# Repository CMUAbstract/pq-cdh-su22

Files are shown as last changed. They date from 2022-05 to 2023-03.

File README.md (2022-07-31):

# Pocketqube Command and Data Handling Board

Pocketqube command and data handling board

**Dependencies**

```bash
sudo apt install build-essential cmake gcc git libusb-1.0-0 libusb-1.0-0-dev libgtk-3-dev
cd $HOME/git-repos/cote/scripts
./setup_dependencies.sh $HOME/sw
```

## Useful link

* [libopencm3](http://libopencm3.org/docs/latest/stm32l4/html/modules.html) : STM open source firmware link

## Directory Contents

* [3d-models](3d-models/README.md): Contains copies of `.stp` 3D model files
* [components](components/README.md): Contains copies of `.lib` component files
* [datasheets](datasheets/README.md): Contains component datasheets
* [footprints](footprints/README.md): Contains copies of `.kicad_mod` footprint
  files
* [gerbers](gerbers/README.md): Contains the most recent set of Gerber files
* [kicad](kicad/README.md): Contains the KiCad project files
* [versions](versions/README.md): Contains `.zip` files of Gerber files
  submitted for manufacture
* [BOM.csv](BOM.csv): Bill of materials
* [LICENSE](LICENSE): License
* [NOTES.md](NOTES.md): Step-by-step instructions for setting up KiCad,
  designing the board, and exporting Gerber files for manufacture
* [README.md](README.md): This document

## License

Written by Bradley Denby  
Other contributors: None

## Update

PQ-CDH Version 0.1.0 : 

1. Transferred design scheamtic and PCB from Kicad5 to Kicad6
2. Mounting holes adjustment same as referred to comm-401 board.
3. Reduced board dimension 43 x 43 mm
4. Removing 5th Pin from upper and lower right

PQ-CDH Version 0.1.1

1. Changed VDD, GND, SWDIO, and SWCLK to lower left to right 4 pins
2. Changed "PQ CDH v0.1.0" to "PQ CDH v0.1.1"
3. Adjusted controller and Conn_02x06_Odd_Even, for mounting hole clearance.
4. Adjusted Conn_02x06_Odd_Even in vertically aligned along with aligned to top and bottom connector holes.
5. Addition of 4 testpads added between oscillator and its capacitor.

PQ-CDH Version 0.2.0

1. I2C3 SDA and SCL to pins 1 and 2 on the bottom header row
2. ADC to pin 3 on the bottom header row
3. unused GPIO to pins 4 and 5 on bottom header row

See the top-level [LICENSE](LICENSE) file for the license.

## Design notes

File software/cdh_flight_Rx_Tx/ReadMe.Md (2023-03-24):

# FLATSAT DEMO CODE : CDH

This repositry includes support for openLST TAB communication protocol
1. Generates control signal for EPS board to control COM board power supply.
2. Receives TAB commands over UART, parses TAB commands to formulate reply and sends TAB commands over UART.
3. Control CDH LEDs for TAB commmands reception, enables debugging.

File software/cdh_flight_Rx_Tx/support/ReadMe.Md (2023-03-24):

# Support Includes : Flatsat DEMO CDH

- `bootloader` : Tartan Artibeus EXPT board bootloader implementation file - USART1 Tx, Rx for TAB command receive, parse response and reply.
- `commands` : Tartan Artibeus EXPT board commands file
- `support` : Tartan Artibeus CDH board UART support implementation - init clock, init led, init uart
- `taolst_protocol`: Tartan Artibeus OLST serial communication protocol implementation - Rx/Tx Buffer and commands

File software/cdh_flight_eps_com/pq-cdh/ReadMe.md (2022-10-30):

Support file : iniialisation for Clock, UART and LED pins

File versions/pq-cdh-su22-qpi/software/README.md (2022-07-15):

# Command and Data Handling Board Software

Command and data handling board software

**Usage**

Change directories to one of the software folders, e.g. `blink`, and execute
`make`. The Makefile includes the rules.mk file, as well as libopencm3 and any
common ASM or C files. Be sure to source `sourcefile.txt` first.

```bash
# Example
cd $HOME/git-repos/pq-cdh-su22/scripts/
source sourcefile.txt
cd $HOME/git-repos/pq-cdh-su22/software/blink/
make
```

See the README in each program directory for details.

## Directory Contents

* [blink](blink/README.md): Makes the Tartan Artibeus EXPT board LEDs blink
* [rules.mk](rules.mk): Used by `make`
* [README.md](README.md): This document

## License

Written by Bradley Denby  
Other contributors: None

See the top-level LICENSE file for the license.

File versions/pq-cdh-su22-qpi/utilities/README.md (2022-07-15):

# Utilities

This directory contains utilities. The setup script places the stlink software
and the ARM GCC compiler in this directory.

## Directory Contents

* [README.md](README.md): This document

## License

Written by Bradley Denby  
Other contributors: None

See the top-level LICENSE file for the license.

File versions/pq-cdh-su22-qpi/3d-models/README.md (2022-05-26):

# 3D Models

3D model files for board components

## Directory Contents

* [README.md](README.md): This document

## License

Written by Bradley Denby  
Other contributors: None

See the top-level [../LICENSE](LICENSE) file for the license.

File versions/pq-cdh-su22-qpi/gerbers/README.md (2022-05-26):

# Gerbers

Gerber files for the most recent board version

## Directory Contents

* [README.md](README.md): This document

## License

Written by Bradley Denby  
Other contributors: None

See the top-level [../LICENSE](LICENSE) file for the license.

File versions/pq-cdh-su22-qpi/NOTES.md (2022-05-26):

# Notes for KiCad

* Install the correct version.

```bash
sudo add-apt-repository ppa:kicad/kicad-6.0-releases
sudo apt update
sudo apt install kicad
```

* Open KiCad. If prompted, start with default settings.

* Choose `File > New Project from Template...`. Select the project location.
  **Un-check "Create a new directory for the project" (bottom left)** and type
  the project name in the top text box (here: `pq-cdh`). Choose "Save."

* Launch the Schematic Editor. If prompted, accept "Copy default global symbol
  library table (recommended)." Choose `File > Page Settings...` and select
  "Size: USLetter 8.5x11in" if not already selected. Choose `File > Save`.

* Open the Symbol Editor by choosing `Tools > Symbol Editor` from the Schematic
  Editor.

* Using the Symbol Editor, choose `File > New Library...`. Choose the "Project"
  scope when prompted. Use the project name (here: `pq-cdh`), and choose "Save."

* Import the BOM symbols provided by `componentsearchengine.com` (free account
  required). Select `File > Import Symbol...` and save in the project library
  (be sure to select the project library for symbol import). Copies of the
  `.lib` files should be placed in the `components/` directory.

* Open the Footprint Editor. Accept "Copy default global footprint library table
  (recommended)" if prompted. Choose `File > New Library...`. Choose the
  "Project" scope when prompted. Use the project name (here: `pq-cdh`), and
  choose "Save."

* Import the BOM footprints from `componentsearchengine.com` into the project
  footprint library. Right-click on the footprint library, and select
  `Import Footprint...`. Copies of the `.kicad_mod` files should be placed in
  the `footprints/` directory. Choose `File > Save`, select the footprint
  library, and choose "Save."

* For each footprint, associate the corresponding 3D model from the `3d-models/`
  directory. Choose `File > Footprint Properties...` and specify the path to the
  3D model file under the 3D Settings tab using the folder icon. Save changes.

* Lay out the schematic in the Schematic Editor. Set the appropriate label
  values.

* In the Schematic Editor, select `Tools > Annotate Schematic...` and choose
  "Entire schematic;" "Keep existing annotations;" "Sort symbols by X position;"
  and "Use first free number after 0."

* Also in the Schematic Editor, choose `Tools > Assign Footprints...` and set
  the footprints.

* Specify footprints that cannot be set automatically, e.g.:
  `Conn_01x04 : pq:PinSocket_4x1_Pocketqube`, and
  `Conn_01x16 : pq:PinSocket_1x16_Pocketqube`, and
  `Conn_01x04 : pq:MountingHoles_Pocketqube`

* Open the PCB Editor and choose `File > Page Settings...` to select
  "Size: USLetter 8.5x11in" if not already selected. Choose `File > Save`.

* Choose `File > Board Setup...` and under "Layers," choose "Four layers, parts
  on Front & Back." Enable the following layers: `F.CrtYd`, `F.Fab`, `F.Paste`,
  `F.SilkS`, `F.Mask`, `F.Cu`, `In1.Cu`, `In2.Cu`, `B.Cu`, `B.Mask`, `B.SilkS`,
  `B.Paste`, `B.Fab`, `B.CrtYd`, `Edge.Cuts`, and `Margin`. For simplicity, set
  `In1.Cu` and `In2.Cu` to power layers and keep the other two layers as signal
  layers. Set the PCB thickness to 1.742 mm.

* Choose `Preferences > Preferences...`. Under `Pcbnew`, set Units to Inches.

* Choose `File > Board Setup...`. Under `Design Rules`, choose
  `Solder Mask/Paste`. Set "Solder mask clearance" to 0.0005 in (i.e. 0.5 mils
  or 0.0127 mm), and set all other values to zero.

* Still under `File > Board Setup...`, choose `Design Rules`. Ensure that "Allow
  blind/buried vias" is **not** checked. Ensure that "Allow micro vias (uVias)"
  is **not** checked. Set the following minimum values:
  * Minimum track width: 5 mils
  * Minimum via diameter: 18 mils
  * Minimum via drill: 10 mils
  * Minimum uVia diameter: 18 mils
  * Minimum uVia drill: 10 mils
  * Minimum hole to hole: 5 mils

* Still under `File > Board Setup...`, choose `Net Classes` under
  `Design Rules`. Double-click at the top of the entry area under "Net Classes"
  and edit the Default values:
  * Clearance: 5 mils
  * Track Width: 5 mils
  * Via Size: 18 mils
  * Via Drill: 10 mils
  * uVia Size: 18 mils
  * uVia Drill: 10 mils
  * dPair Width: 5 mils
  * dPair Gap: 5 mils

* Still under `File > Board Setup...`, choose `Tracks & Vias` under
  `Design Rules`. Add an 8 mils Tracks Width (for VDD and GND).

* Choose `Preferences > Preferences...`. Under `Pcbnew`, set Units to
  Millimeters.

* Add the PCB outline with graphic lines and graphic arcs.

**Graphic Lines for PCB Edge**

Create the following in the Edge.Cuts layer:
* Start: (136.04, 86.50); End: (173.96, 86.50)
* Start: (136.04,129.50); End: (173.96,129.50)
* Start: (133.50, 89.04); End: (133.50,126.96)
* Start: (176.50, 89.04); End: (176.50,126.96)

**Graphic Arcs for PCB Edge**

Create the following in the Edge.Cuts layer:
* Center: (136.04, 89.04); Start: (136.04, 86.50); Arc angle -90.0
* Center: (173.96, 89.04); Start: (176.50, 89.04); Arc angle -90.0
* Center: (136.04,126.96); Start: (133.50,126.96); Arc angle -90.0
* Center: (173.96,126.96); Start: (173.96,129.50); Arc angle -90.0

* In the Schematic Editor, choose `File > Export > Netlist...` and select
  "Export Netlist."

* In the PCB Editor, choose `File > Import > Netlist...` and browse to the
  appropriate file.

* Place the components, tracks, ground plane, and silkscreen labels.

* Record component characteristics:
  * J1:   (155.00,  88.95) @   0.0 (Example 1)
  * J2:   (155.00, 127.05) @   0.0 (Example 2)
  * J3:   (135.95, 120.70) @ 180.0 (Example 3)
  * J4:   (170.24, 108.00) @ 180.0 (Example 4)
  * J5:   (155.00, 108.00) @   0.0 (Example 5)

* Record via positions:
  * GND: (137.30, 111.30) (Example)

* Ground and power planes (Add filled zones):
  * Clearance: 0.254 mm
  * Minimum width: 0.127 mm
  * Thermal clearance: 0.254 mm
  * Thermal spoke width: 0.254 mm

* Silkscreen labels (Width: 0.5 mm; Height: 0.5 mm; Thickness: 0.1 mm):

## Generating Gerbers

* Ensure that fill zones have been redrawn, e.g. by running DRC (the bug icon)
* Choose `File > Plot...` from the PCB Editor
  * Output directory: ../gerbers/
  * Included Layers: F.Cu, B.Cu, F.Silkscreen, B.Silkscreen, F.Mask, B.Mask,
    Edge.Cuts
  * General Options: Plot footprint values, Plot reference designators
  * Gerber Options: Generate Gerber job file
* Choose "Plot"
* Choose "Generate Drill File"
  * Output folder: ../gerbers/
  * Drill File Format: Excellon, PTH and NPTH in single file, Oval Holes Drill
    Mode: Use route command (recommended)
  * Map File Format: PostScript
  * Dill Origin: Absolute
  * Drill Units: Inches
  * Zeros Format: Decimal format (recommended)
* Choose "Generate Drill File"

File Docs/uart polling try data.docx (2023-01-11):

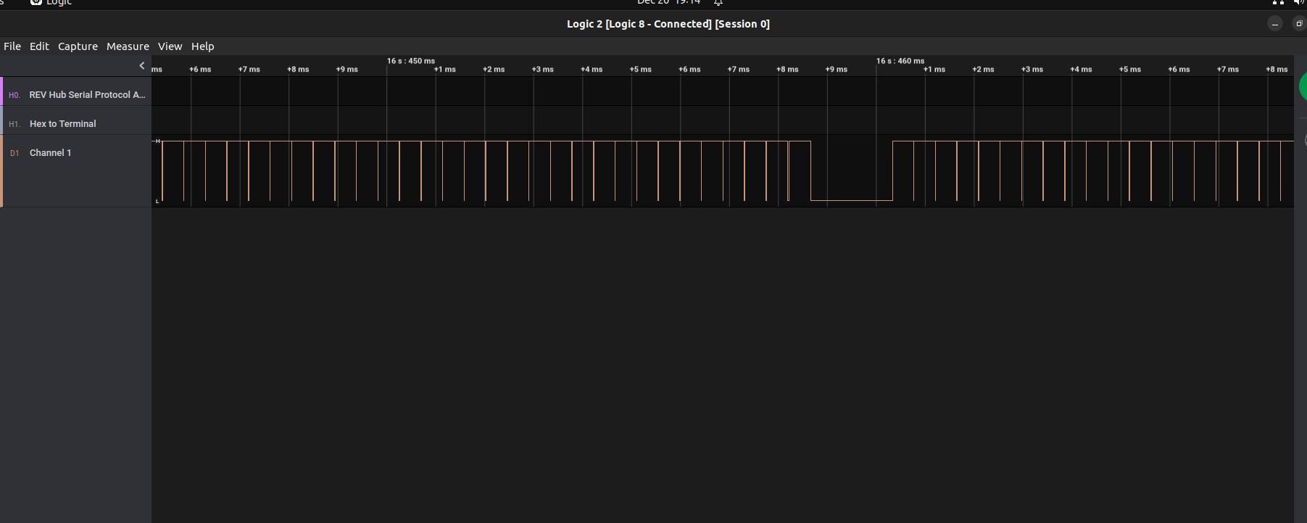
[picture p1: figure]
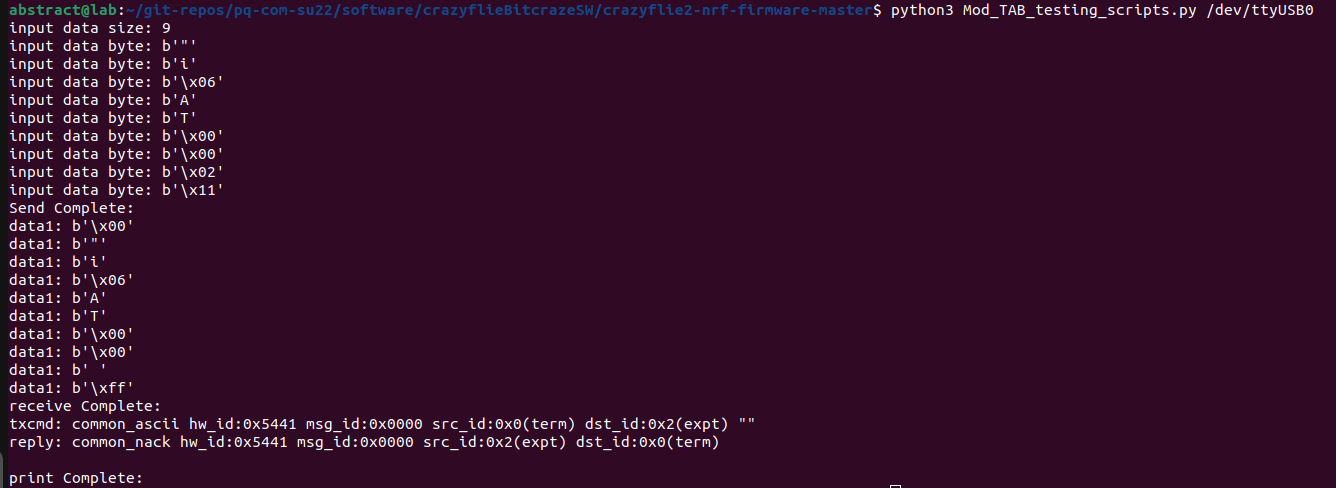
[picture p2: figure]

As

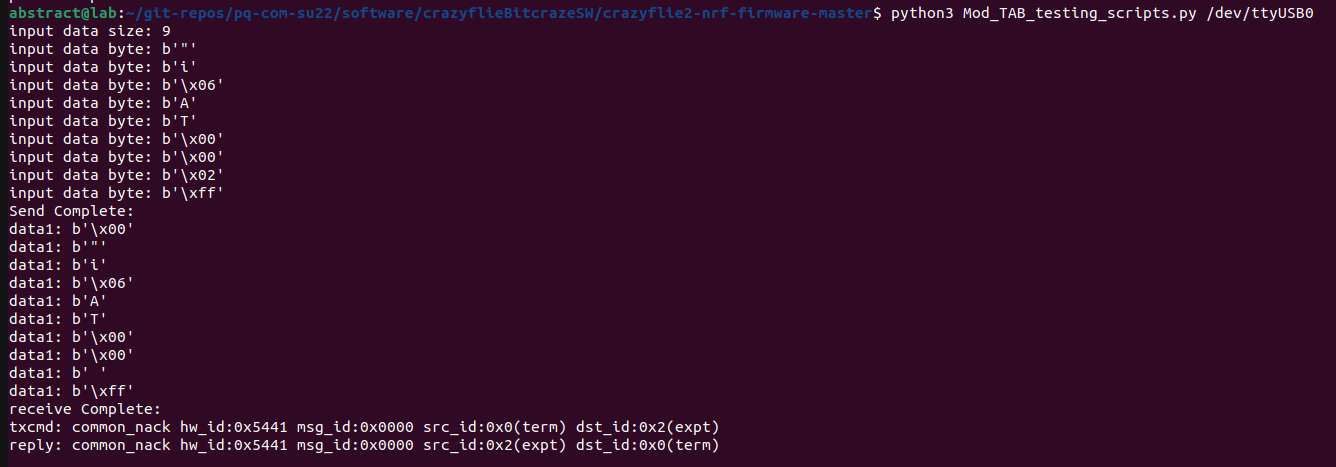
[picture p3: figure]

as

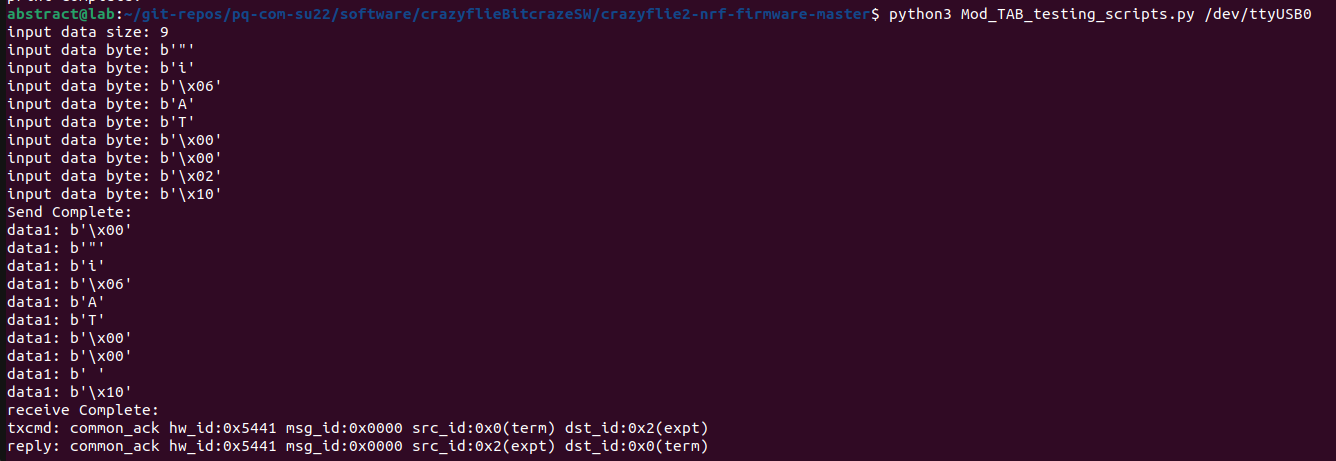
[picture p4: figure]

as

COM Board Response

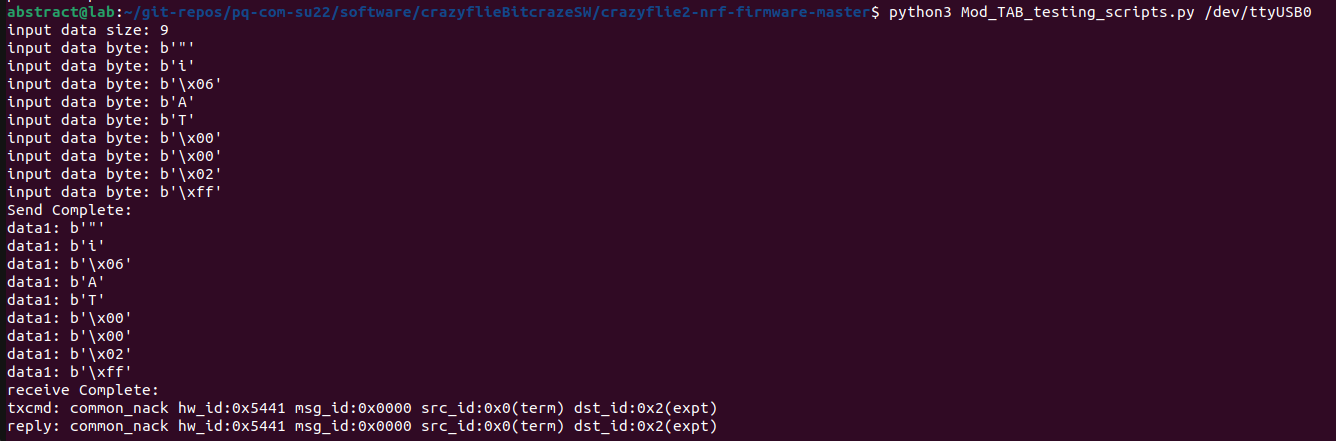
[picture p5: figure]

as

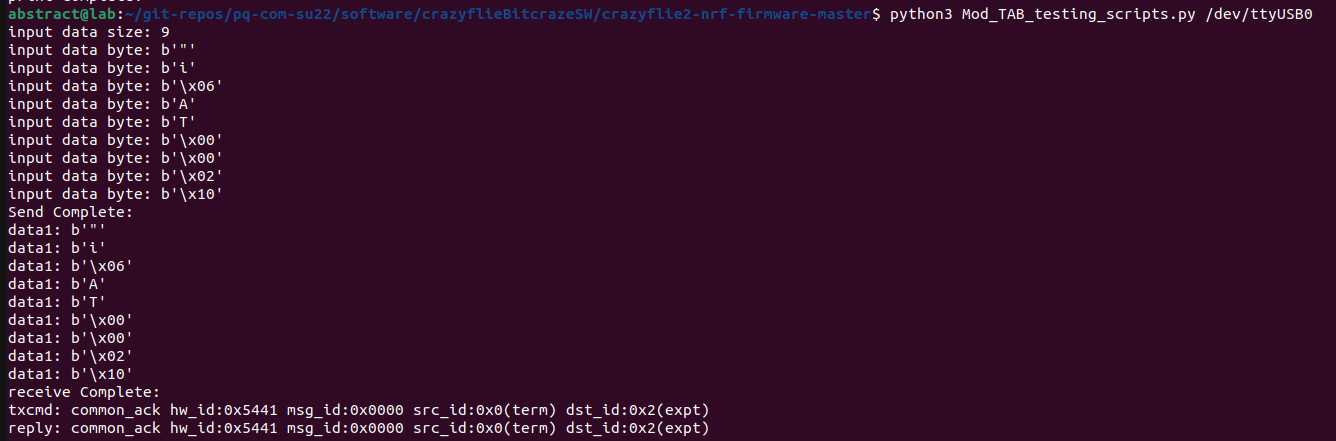
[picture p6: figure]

as

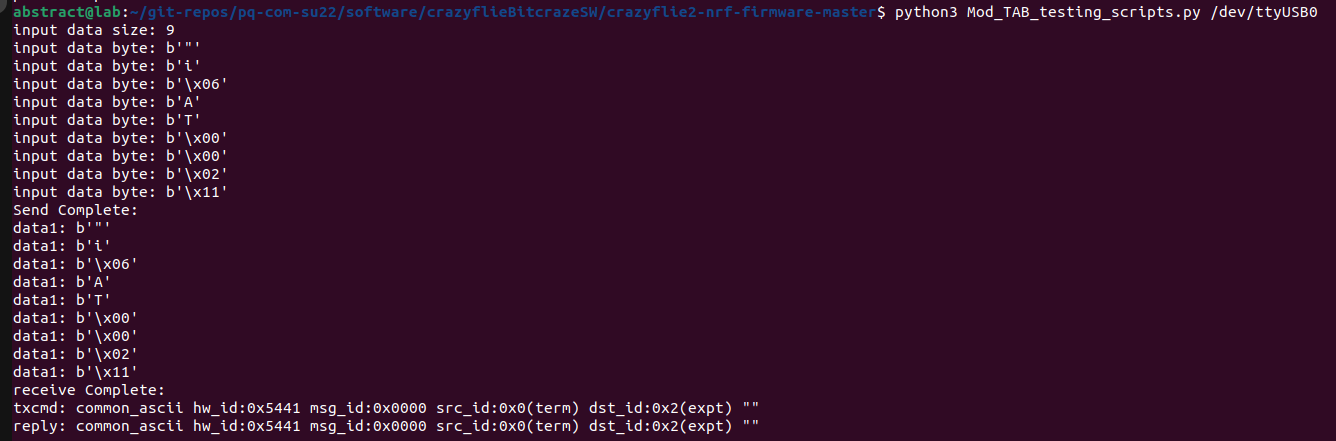
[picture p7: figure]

as

eps+com+cdh

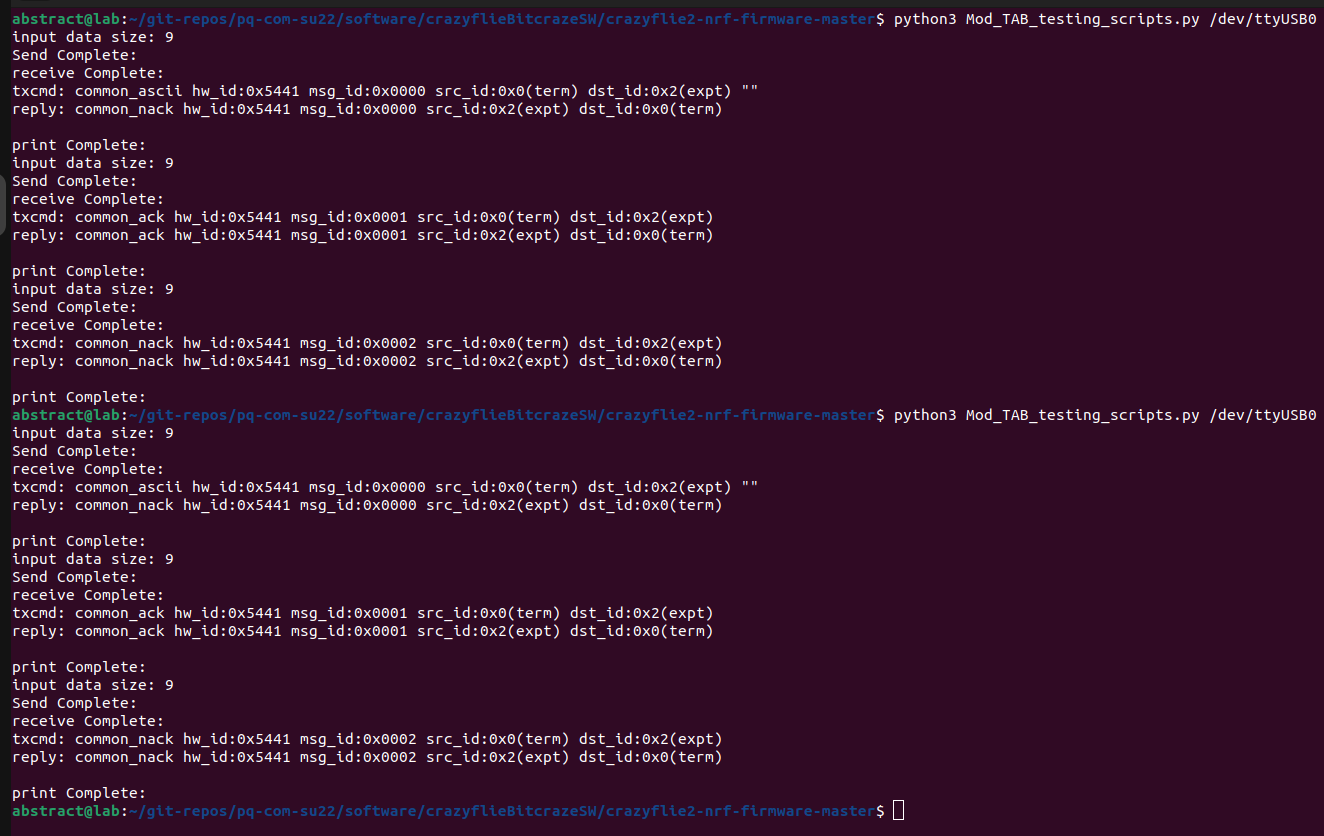
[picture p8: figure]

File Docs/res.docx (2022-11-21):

comm

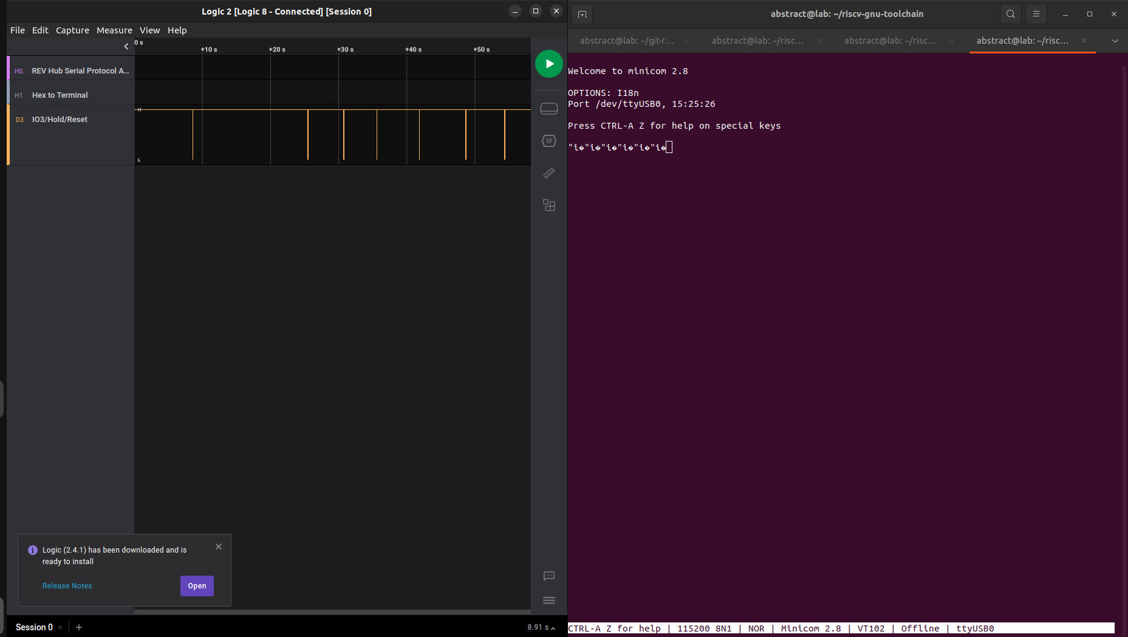
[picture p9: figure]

cdhcomm

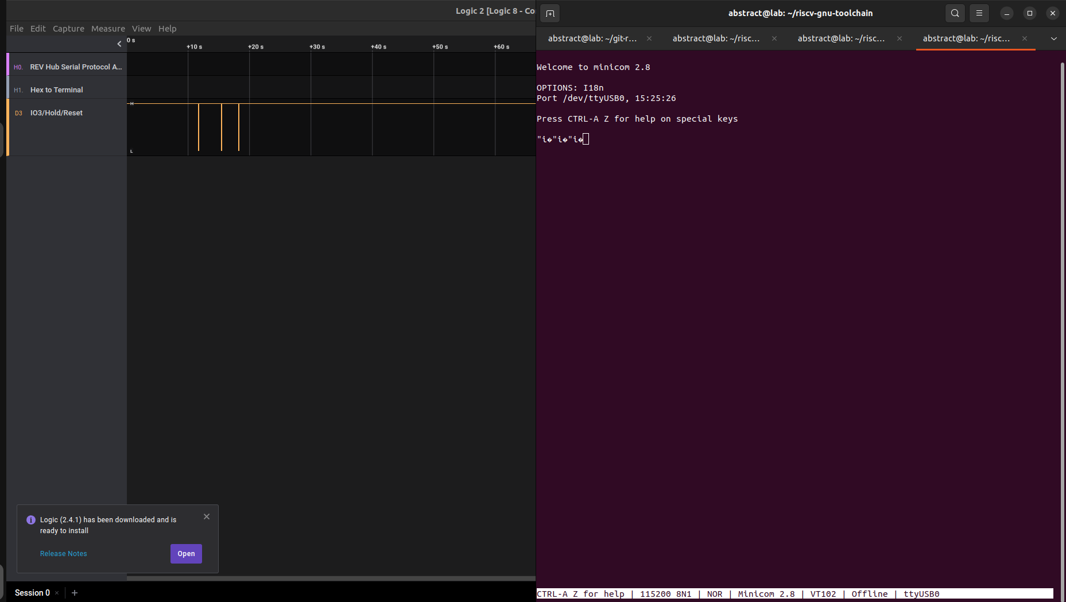
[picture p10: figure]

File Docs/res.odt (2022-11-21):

comm


cdhcomm


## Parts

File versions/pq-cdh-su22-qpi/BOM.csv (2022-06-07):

Label | Order Status | Count | Mfr Id | Mouser Id | Componentsearchengine.com url | Description | Manufacturer_Name | Manufacturer_Part_Number
C1 | NA | 1 | GRM188C71A475KE21D | 81-GRM188C71A475KE2D | https://componentsearchengine.com/part-view/GRM188C71A475KE21D/Murata%20Electronics | Multilayer Ceramic Capacitors MLCC - SMD/SMT | Murata Electronics | GRM188C71A475KE21D
C2, C3, C4, C7, C9, C14 | Ordered (Mouser) | 6 | 0603ZC104JAT2A | 581-0603ZC104JAT2A | https://componentsearchengine.com/part-view/0603ZC104JAT2A/AVX | Multilayer Ceramic Capacitors MLCC - SMD/SMT 10V .1uF X7R 0603 5% | AVX | 0603ZC104JAT2A
C5, C6 | In CART (Kynix) | 2 | 0603ZC105JAT2A | 581-0603ZC105JAT2A | https://componentsearchengine.com/part-view/0603ZC105JAT2A/AVX | Multilayer Ceramic Capacitors MLCC - SMD/SMT FACTORY NOT ACCEPTING ORDERS | AVX | 0603ZC105JAT2A
C8 | In CART (Newark) | 1 | GRM1857U1A103JA44D | 81-GRM1857U1A103JA4D | https://componentsearchengine.com/part-view/GRM1857U1A103JA44D/Murata%20Electronics | Capacitor GRM18_0.10 L=1.6mm W=0.8mm T=0.5mm | Murata Electronics | GRM1857U1A103JA44D
C10, C11, C12, C13 | Ordered (Mouser) | 4 | 0603ZA220JAT2A | 581-0603ZA220JAT2A | https://componentsearchengine.com/part-view/0603ZA220JAT2A/AVX | Multilayer Ceramic Capacitors MLCC - SMD/SMT 10V 22pF C0G 0603 5% Tol | AVX | 0603ZA220JAT2A
C15 | Ordered (Mouser) | 1 | 597D158X9004R2T | 71-597D158X9004R2T | https://componentsearchengine.com/part-view/597D158X9004R2T/Vishay | Cap for MCU VBAT; 1500 uF +/- 10 %; 4 VDC; 15 mOhm ESR; 60 uA leakage current; -55 - +125 C | Vishay | 597D158X9004R2T
FB1 | In CART (Kynix) | 1 | MMZ1608S601ATD25 | 810-MMZ1608S601ATD25 | https://componentsearchengine.com/part-view/MMZ1608S601ATD25/TDK | Ferrite Beads Multi-Layer 600Ohm 25% 100MHz 500mA 350mOhm DCR 0603 Automotive T/R | TDK | MMZ1608S601ATD25
IC1 | Back-Ordered (Newark) | 1 | STM32L496RGT3 | 511-STM32L496RGT3 | https://componentsearchengine.com/part-view/STM32L496RGT3/STMicroelectronics | STMICROELECTRONICS - STM32L496RGT3 - MCU, ARM CORTEX-M4, 80MHZ, LQFP-64 | STMicroelectronics | STM32L496RGT3
IC2 | Ordered (Mouser) | 1 | IS25LP128F-JBLA3 | 870-IS25LP128F-JBLA3 | https://componentsearchengine.com/part-view/IS25LP128F-JBLA3/Integrated%20Silicon%20Solution%20Inc. | NOR Flash 128M 2.3-3.6V 166Mhz Serial NOR Flash | Integrated Silicon Solution Inc. | IS25LP128F-JBLA3
J1, J3, J4, J8 | - | 4 | Conn_01x04 | Connectors | - | Connectors | - | -
J2, J5 | - | 2 | Conn_01x16 | Connectors | - | Connectors | - | -
J6 | - | 1 | Conn_01x04 | Connectors | - | Connectors | - | -
J7 | - | 1 | Conn_02x06_Odd_Even | Connectors | - | Connectors | - | -
LED1, LED2 | Ordered (Mouser) | 2 | LG_Q396-PS-35 | 720-LGQ396A3964 | https://componentsearchengine.com/part-view/LG%20Q396-PS-35/OSRAM | CHIPLED 0603 GREEN | OSRAM | LG Q396-PS-35
R1, R2, R4 | Ordered (Mouser) | 3 | MCT06030C1001FP500 | 594-MCT06030C1001FP5 | https://componentsearchengine.com/part-view/MCT06030C1001FP500/Vishay | Thin Film Resistors - SMD .1W 1Kohm 1% 0603 50ppm Auto | Vishay | MCT06030C1001FP500
R3, R5 | Ordered (Mouser) | 2 | MCT06030C1002FP500 | 594-MCT06030C1002FP5 | https://componentsearchengine.com/part-view/MCT06030C1002FP500/Vishay | Thin Film Resistors - SMD .1W 10Kohms 1% 0603 50ppm Auto | Vishay | MCT06030C1002FP500
Y1 | Ordered (Mouser) | 1 | ABM8AIG-16.000MHZ-12-2Z-T | 815-ABM8AIG16122ZT | https://componentsearchengine.com/part-view/ABM8AIG-16.000MHZ-12-2Z-T/ABRACON | Crystals 16MHz 12pF 20ppm ESR 70 -40C +125C | ABRACON | ABM8AIG-16.000MHZ-12-2Z-T
Y2 | In CART (Kynix) | 1 | ABS07AIG-32.768kHz-T | 815-S07AIG-32.768T | https://componentsearchengine.com/part-view/ABS07AIG-32.768kHz-T/ABRACON | ABRACON - ABS07AIG-32.768KHZ-T - CRYSTAL, AEC-Q200, 32.768KHZ, 3.2X1.5MM | ABRACON | ABS07AIG-32.768kHz-T

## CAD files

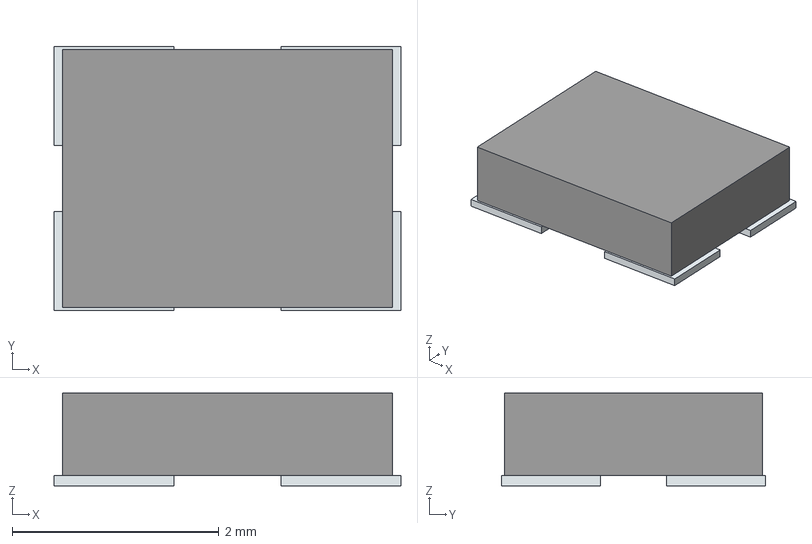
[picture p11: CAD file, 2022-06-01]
versions/pq-cdh-su22-qpi/3d-models/ABM8AIG25000MHZ122ZT3.stp
3.36 x 2.56 x 0.9 mm
Pins

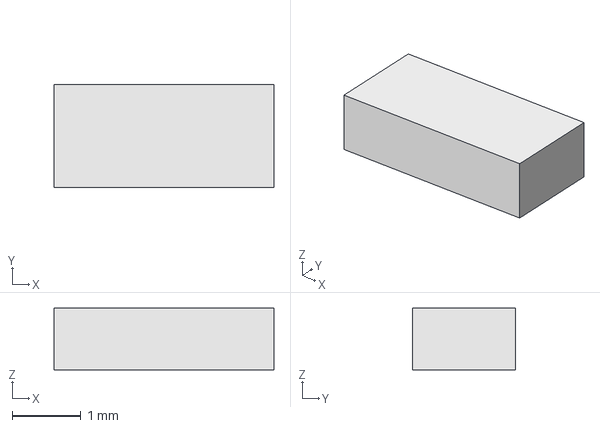
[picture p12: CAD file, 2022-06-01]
versions/pq-cdh-su22-qpi/3d-models/ABS07AIG32768kHz71T.stp
3.20 x 1.50 x 0.9 mm

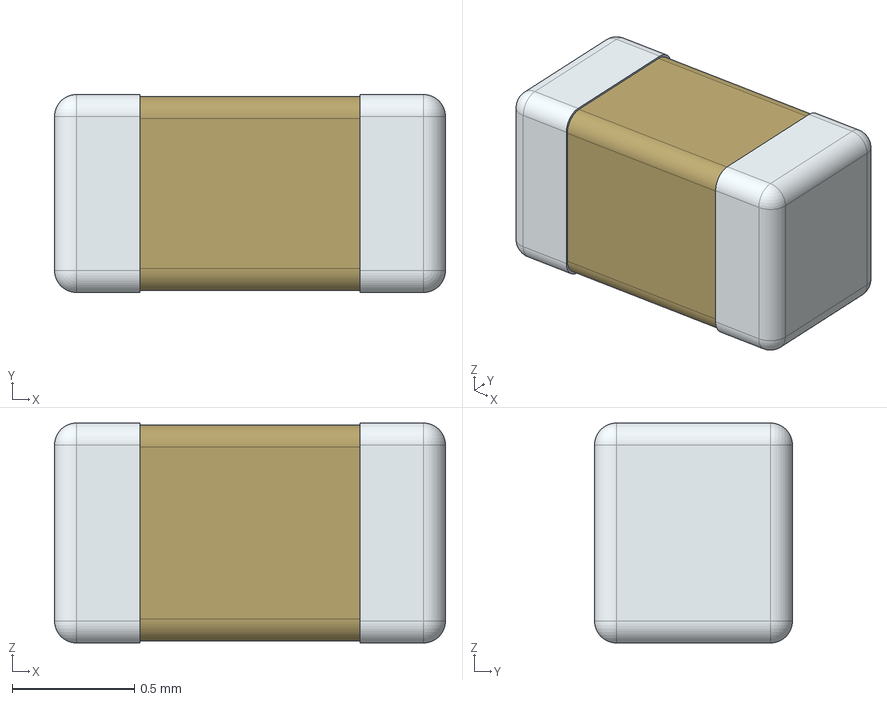
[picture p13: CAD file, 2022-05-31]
versions/pq-cdh-su22-qpi/3d-models/0603ZA220JAT2A.stp
1.60 x 0.81 x 0.9 mm

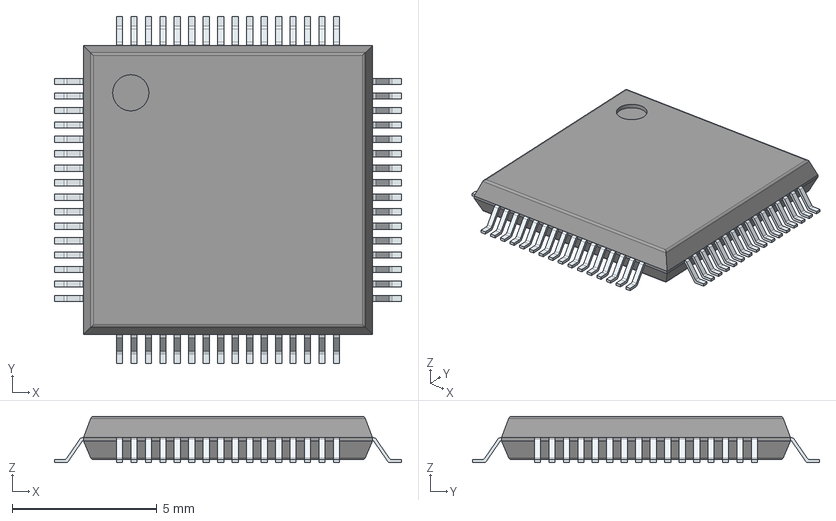
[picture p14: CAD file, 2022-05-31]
versions/pq-cdh-su22-qpi/3d-models/STM32L496RGT3.stp
12.0 x 12.0 x 1.60 mm
PinsArrayLR
PinsArrayTB

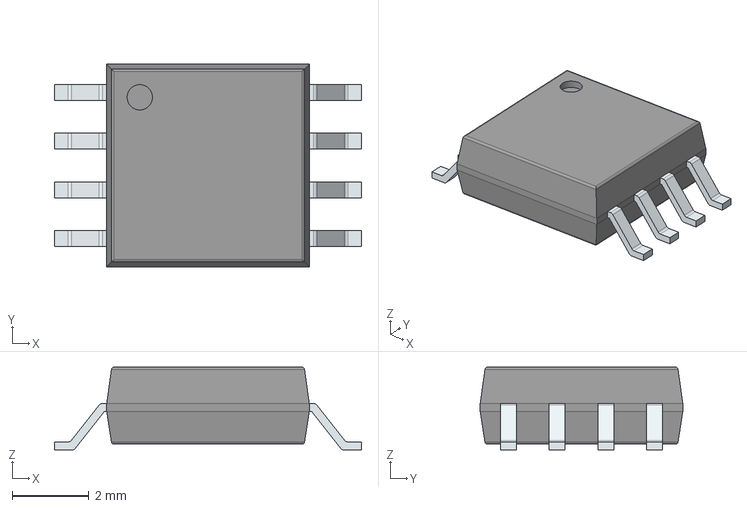
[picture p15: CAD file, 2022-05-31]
versions/pq-cdh-su22-qpi/3d-models/S25FL128LAGMFM010.stp
8.00 x 5.28 x 2.16 mm
PinsArrayLR

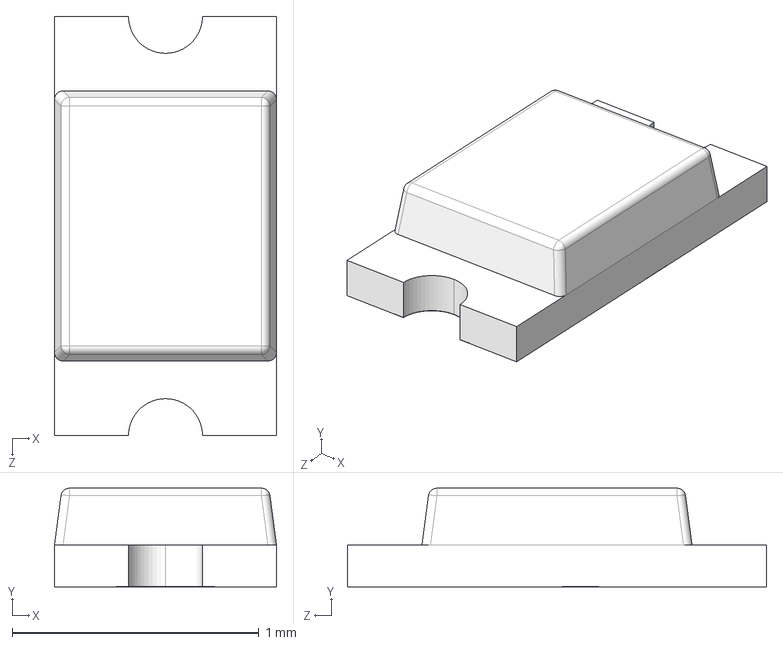
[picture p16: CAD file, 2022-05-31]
versions/pq-cdh-su22-qpi/3d-models/LG_Q396-PS-35.stp
0.9 x 0.4 x 1.70 mm

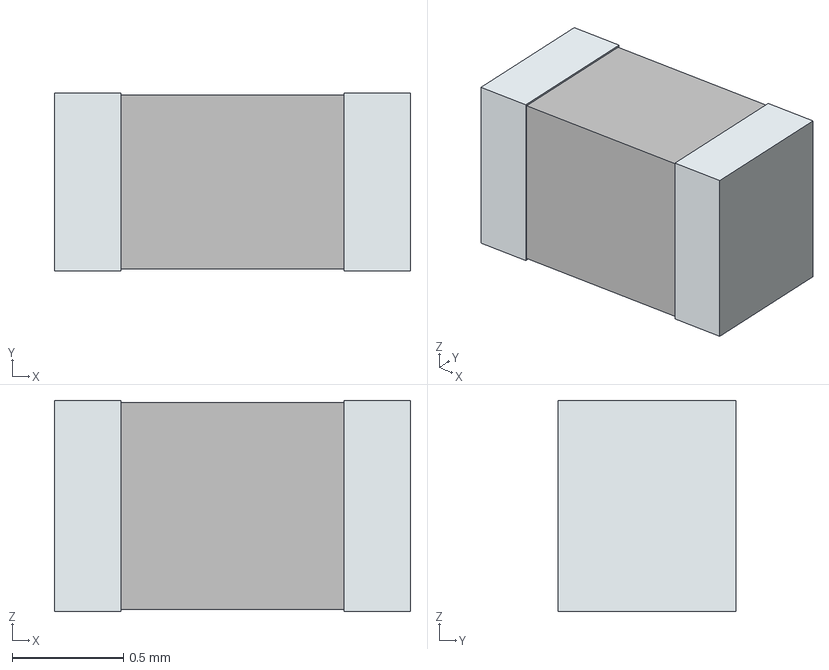
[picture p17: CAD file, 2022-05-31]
versions/pq-cdh-su22-qpi/3d-models/MMZ1608S601ATD25.stp
1.60 x 0.8 x 0.95 mm
term1
term2

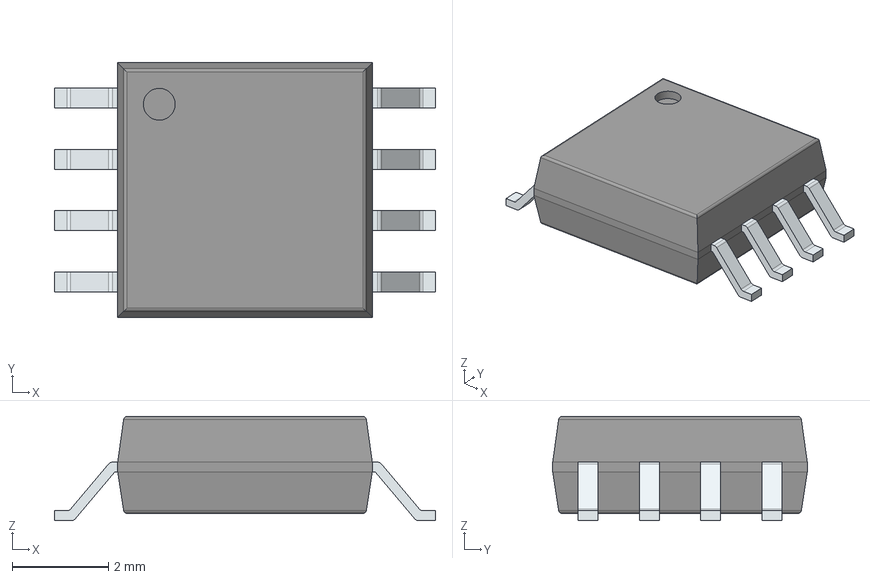
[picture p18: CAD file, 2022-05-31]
versions/pq-cdh-su22-qpi/3d-models/IS25LP128F-JBLA3.stp
7.90 x 5.28 x 2.16 mm
PinsArrayLR

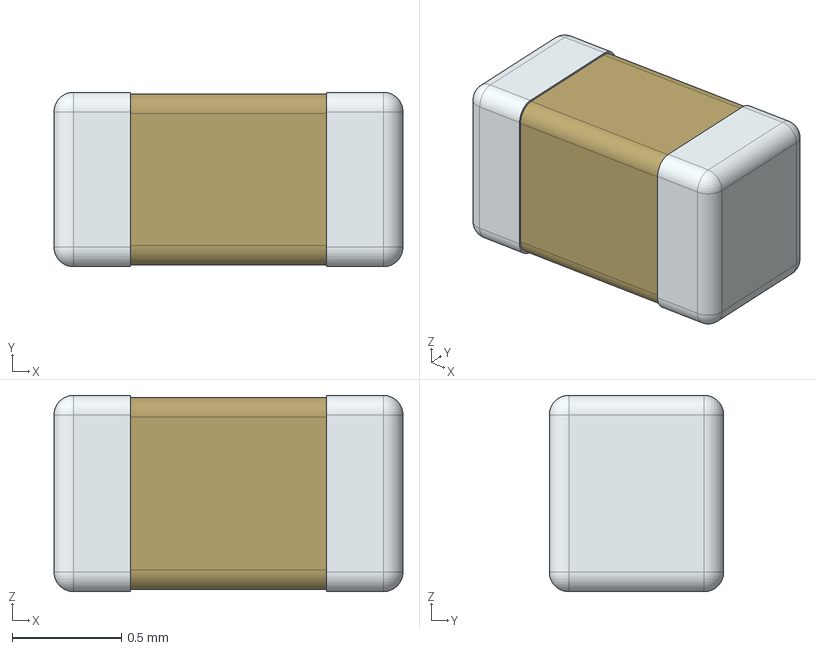
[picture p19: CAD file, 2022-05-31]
versions/pq-cdh-su22-qpi/3d-models/GRM188C71A475KE21D.stp
1.60 x 0.8 x 0.9 mm

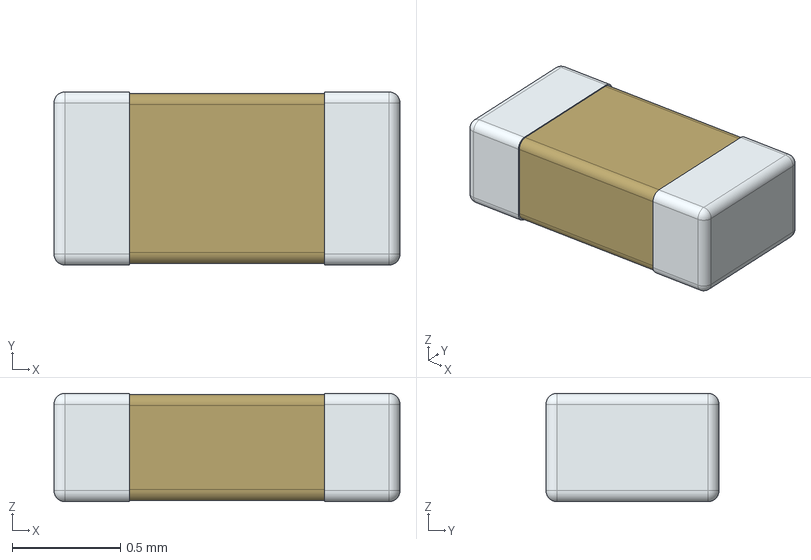
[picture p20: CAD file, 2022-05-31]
versions/pq-cdh-su22-qpi/3d-models/GRM1857U1A103JA44D.stp
1.60 x 0.8 x 0.5 mm

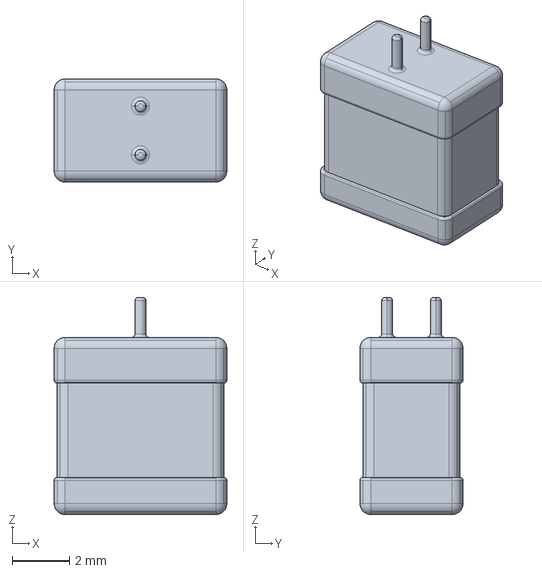
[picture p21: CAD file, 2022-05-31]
versions/pq-cdh-su22-qpi/3d-models/597D158X9004R2T.stp
6.05 x 3.61 x 7.59 mm

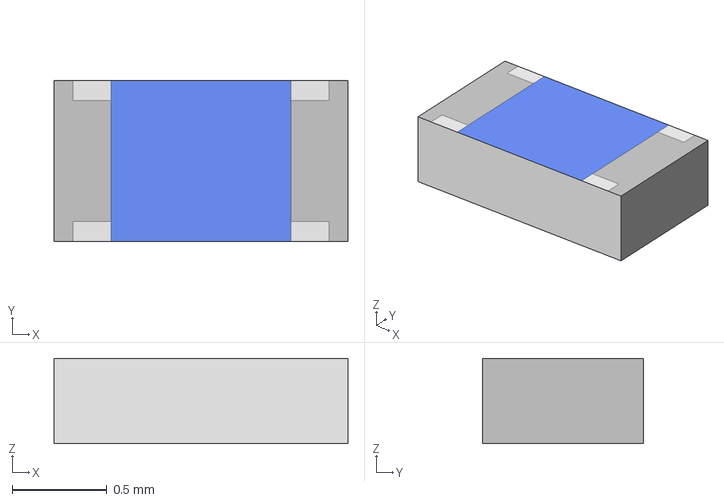
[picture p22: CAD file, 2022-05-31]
versions/pq-cdh-su22-qpi/3d-models/MCT06030C1001FP500.stp
1.55 x 0.85 x 0.45 mm

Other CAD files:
versions/pq-cdh-su22-qpi/3d-models/0603ZC104JAT2A.stp
versions/pq-cdh-su22-qpi/3d-models/0603ZC105JAT2A.stp

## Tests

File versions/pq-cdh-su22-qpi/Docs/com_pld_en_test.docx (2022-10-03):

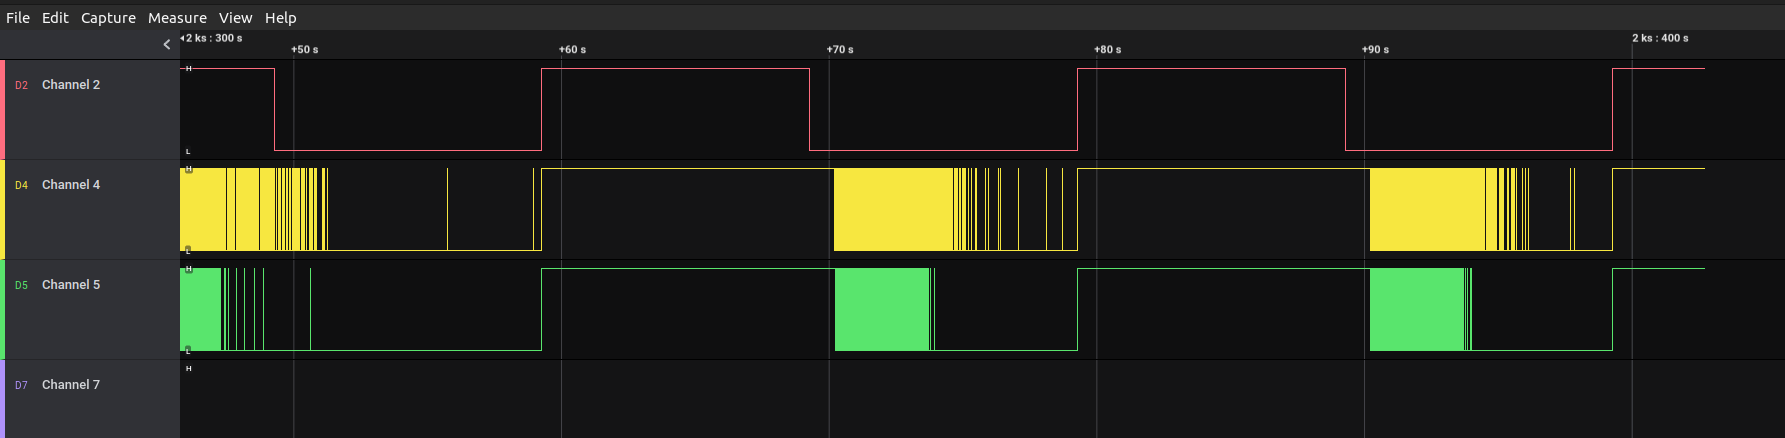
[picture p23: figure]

Vcap:

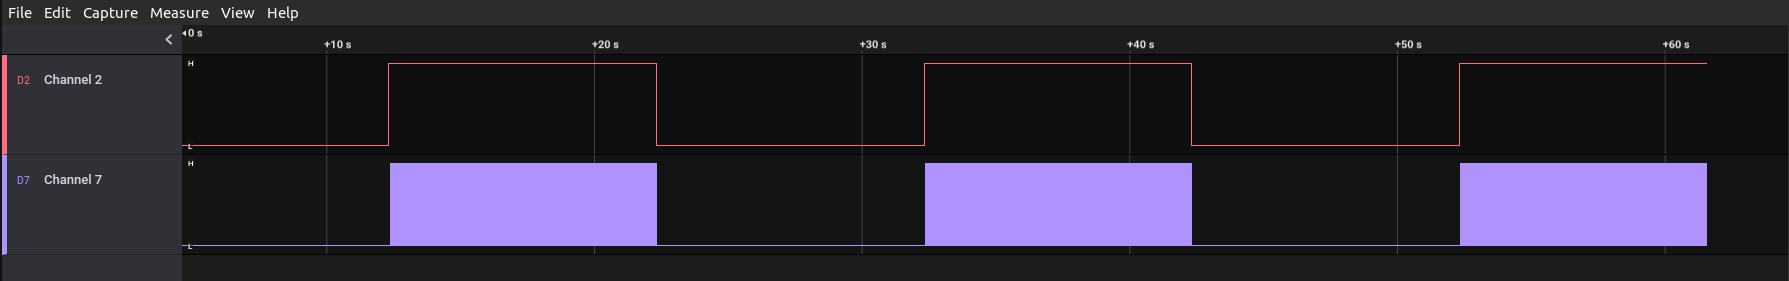
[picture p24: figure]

com_pld_en removed

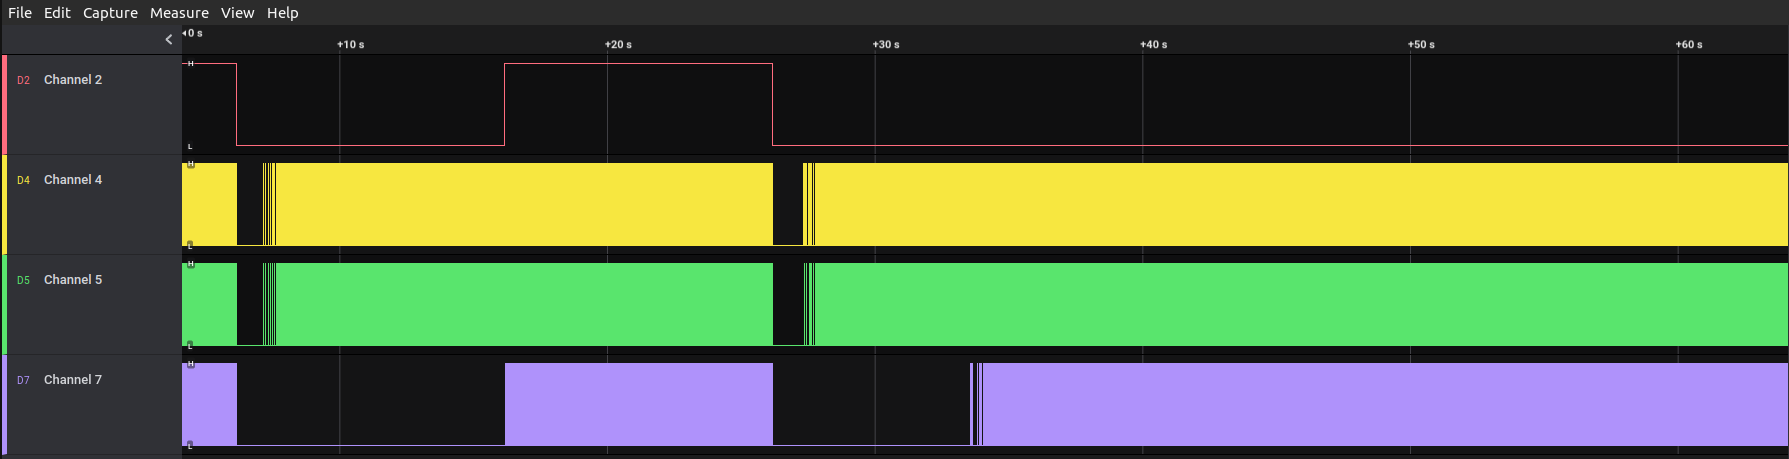
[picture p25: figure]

en on

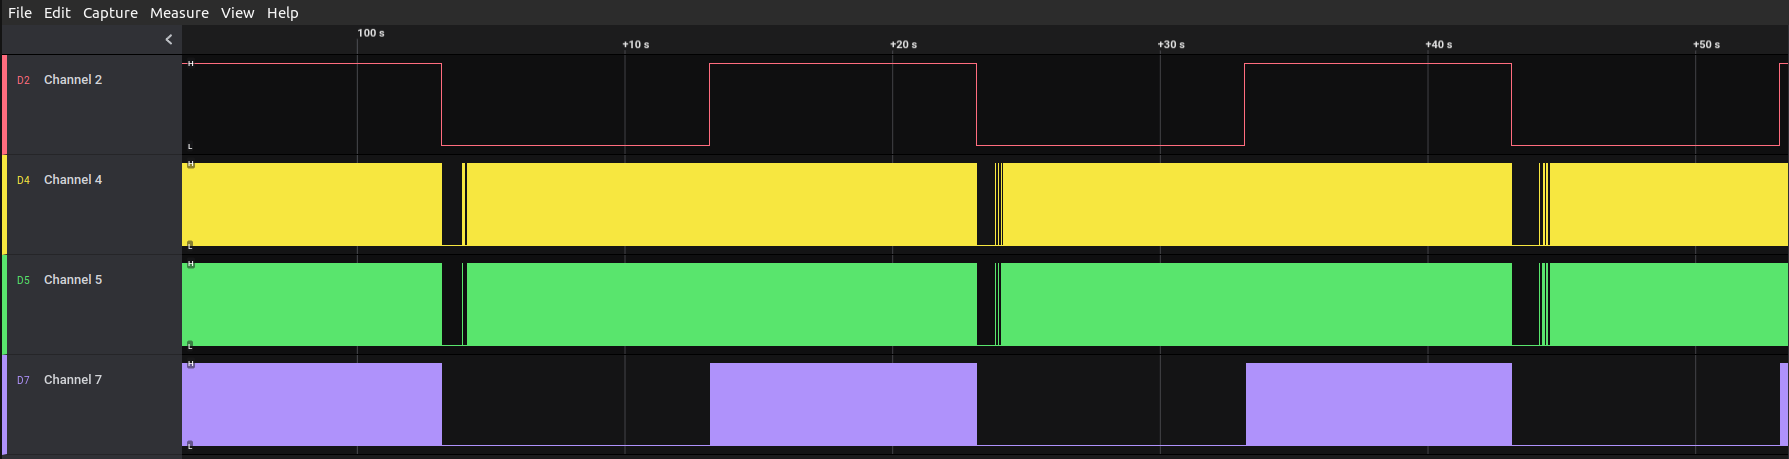
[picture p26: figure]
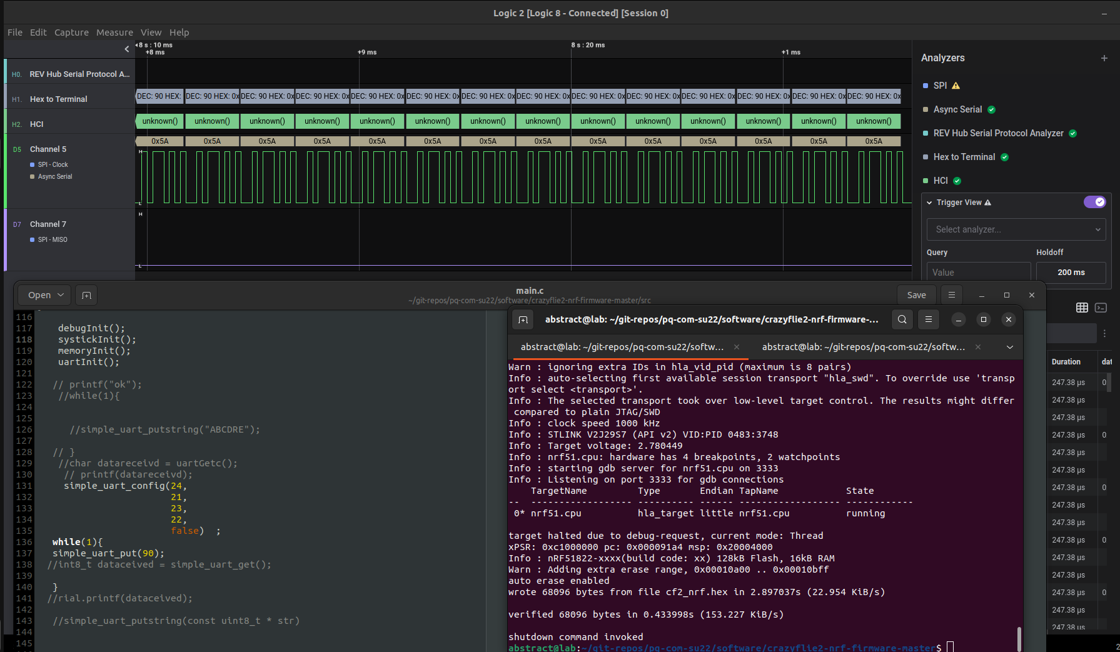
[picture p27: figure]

new

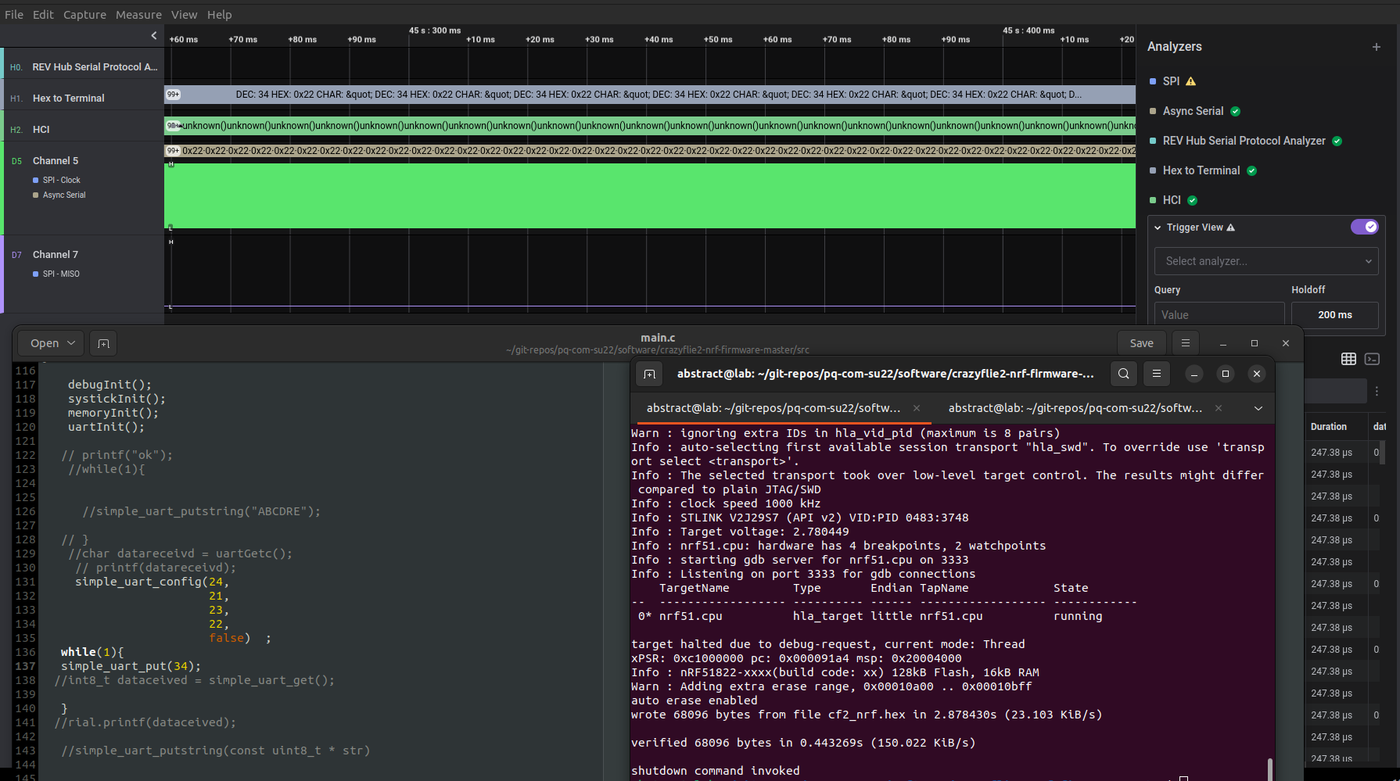
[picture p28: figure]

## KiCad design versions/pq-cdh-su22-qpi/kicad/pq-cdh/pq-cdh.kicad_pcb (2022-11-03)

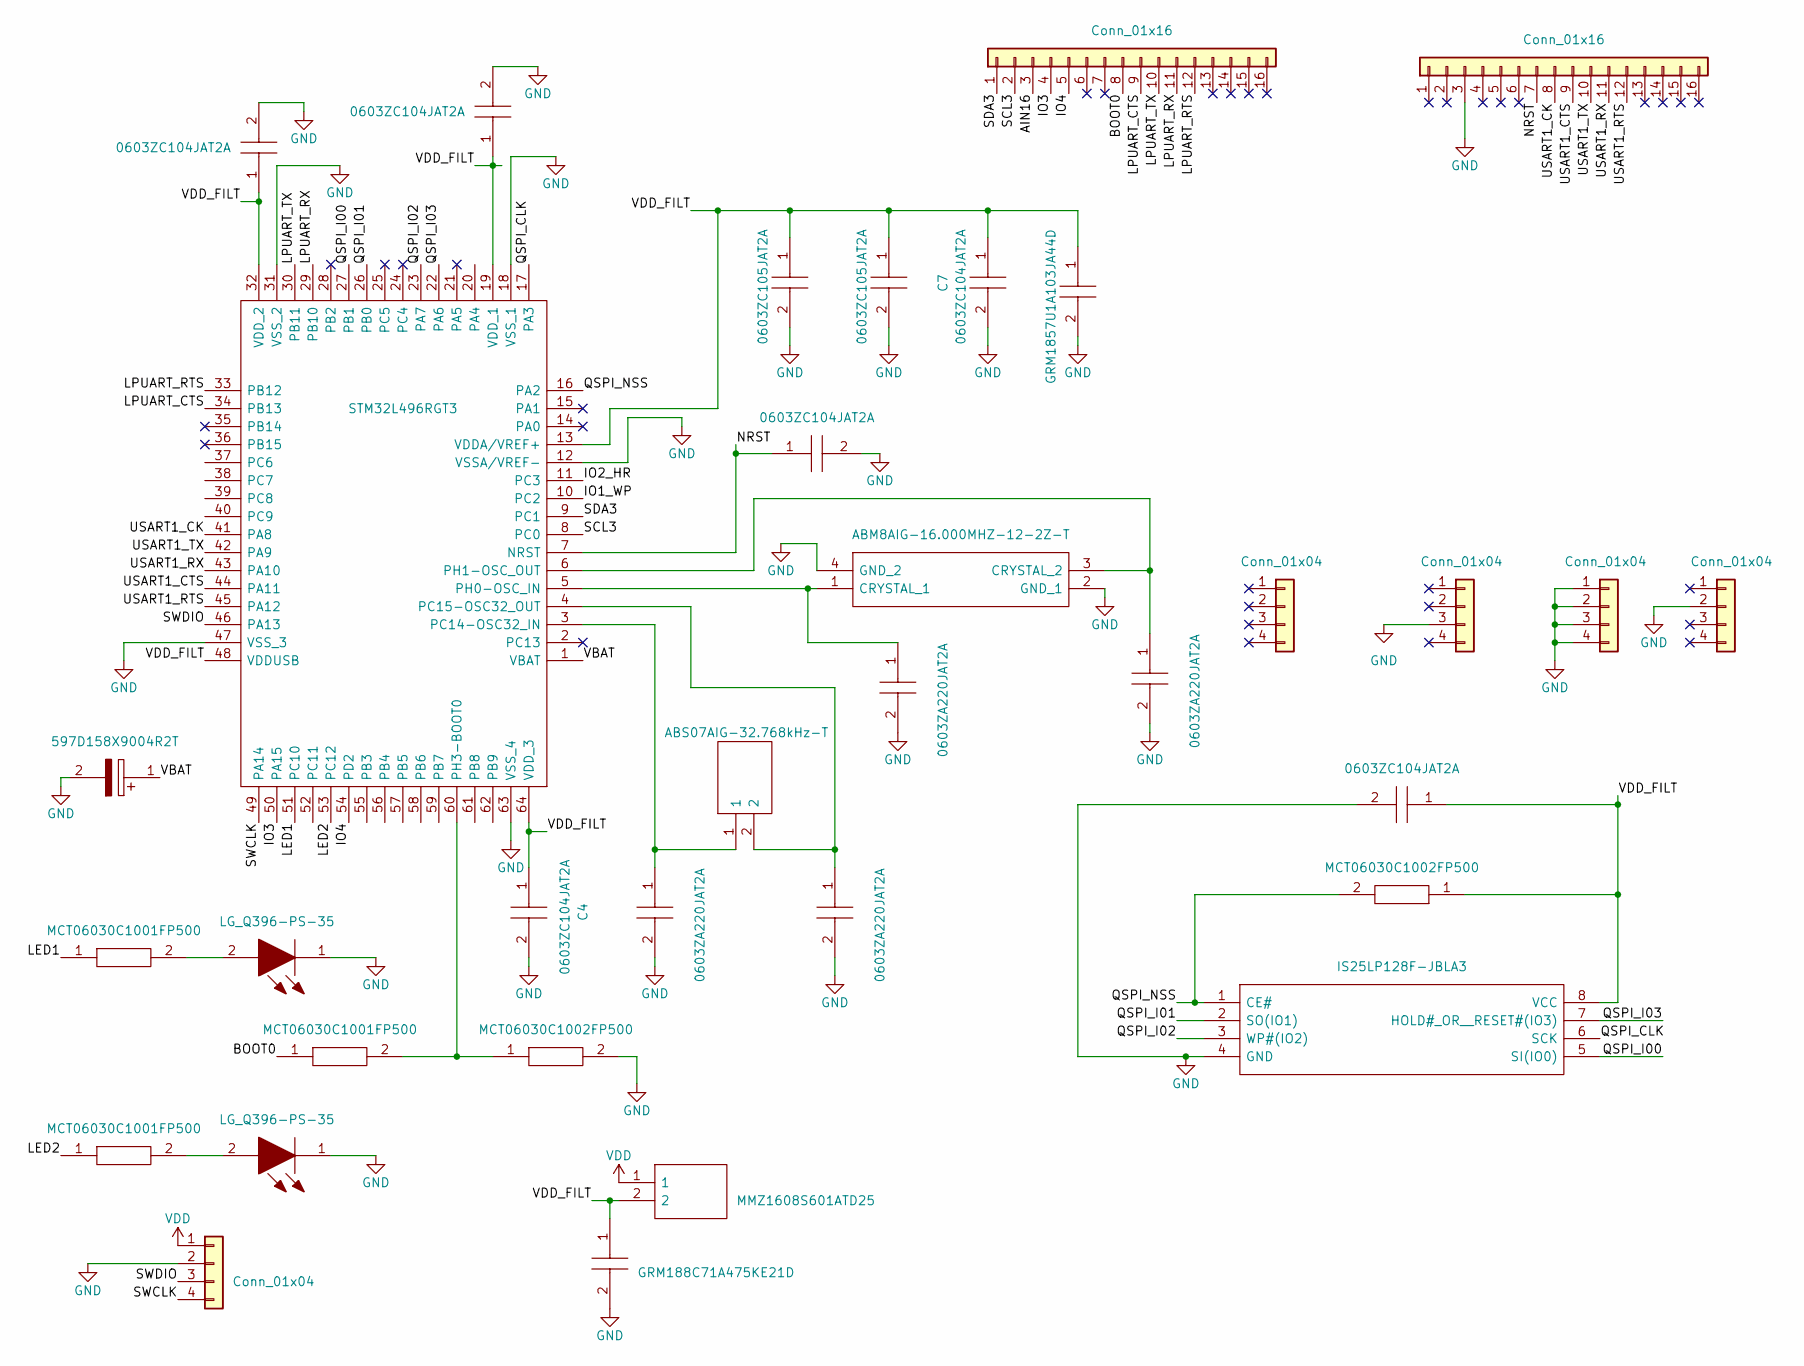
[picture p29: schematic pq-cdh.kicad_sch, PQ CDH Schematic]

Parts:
C1: GRM188C71A475KE21D; CAPC1608X90N; Manufacturer_Part_Number GRM188C71A475KE21D; Mouser Part Number 81-GRM188C71A475KE2D
C2, C3, C4, C7, C9, C14: 0603ZC104JAT2A; CAPC1608X90N; Manufacturer_Part_Number 0603ZC104JAT2A; Mouser Part Number 581-0603ZC104JAT2A
C5, C6: 0603ZC105JAT2A; CAPC1608X90N; Manufacturer_Part_Number 0603ZC105JAT2A; Mouser Part Number 581-0603ZC105JAT2A
C8: GRM1857U1A103JA44D; CAPC1608X50N; Manufacturer_Part_Number GRM1857U1A103JA44D; Mouser Part Number 81-GRM1857U1A103JA4D
C10, C11, C12, C13: 0603ZA220JAT2A; CAPC1608X90N; Manufacturer_Part_Number 0603ZA220JAT2A; Mouser Part Number 581-0603ZA220JAT2A
C15: 597D158X9004R2T; CAPPC5660X400N; Manufacturer_Part_Number 597D158X9004R2T; Mouser Part Number 71-597D158X9004R2T
FB1: MMZ1608S601ATD25; BEADC1608X95N; Manufacturer_Part_Number MMZ1608S601ATD25; Mouser Part Number 810-MMZ1608S601ATD25
IC1: STM32L496RGT3; QFP50P1200X1200X160-64N; Manufacturer_Part_Number STM32L496RGT3; Mouser Part Number 511-STM32L496RGT3
IC2: IS25LP128F-JBLA3; SOIC127P790X216-8N; Manufacturer_Part_Number IS25LP128F-JBLA3; Mouser Part Number 870-IS25LP128F-JBLA3
J1, J3, J4, J8: Conn_01x04; TartanArtibeus_PinSocket_1x4
J2, J5: Conn_01x16; TartanArtibeus_PinSocket_1x16
J6: Conn_01x04; TartanArtibeus_2021_MountingHoles
LED1, LED2: LG_Q396-PS-35; LGQ396PS35; Manufacturer_Part_Number LG Q396-PS-35; Mouser Part Number 720-LGQ396A3964
R1, R2, R4: MCT06030C1001FP500; RESC1608X55N; Manufacturer_Part_Number MCT06030C1001FP500; Mouser Part Number 594-MCT06030C1001FP5
R3, R5: MCT06030C1002FP500; RESC1608X55N; Manufacturer_Part_Number MCT06030C1002FP500; Mouser Part Number 594-MCT06030C1002FP5
Y1: ABM8AIG-16.000MHZ-12-2Z-T; ABM8AIG25000MHZ122ZT3; Manufacturer_Part_Number ABM8AIG-16.000MHZ-12-2Z-T; Mouser Part Number 815-ABM8AIG16122ZT
Y2: ABS07AIG-32.768kHz-T; ABS07AIG32768kHz71T; Manufacturer_Part_Number ABS07AIG-32.768kHz-T; Mouser Part Number 815-S07AIG-32.768T

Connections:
/AIN16: J2.3
/BOOT0: J2.8, R4.1
/IO1_WP: IC1.10 (PC2)
/IO2_HR: IC1.11 (PC3)
/IO3: IC1.50 (PA15), J2.4
/IO4: IC1.54 (PD2), J2.5
/LED1: IC1.51 (PC10), R1.1
/LED2: IC1.53 (PC12), R2.1
/LPUART_CTS: IC1.34 (PB13), J2.9
/LPUART_RTS: IC1.33 (PB12), J2.12
/LPUART_RX: IC1.29 (PB10), J2.11
/LPUART_TX: IC1.30 (PB11), J2.10
/NRST: C9.1, IC1.7 (NRST), J5.7
/QSPI_CLK: IC1.17 (PA3), IC2.6 (SCK)
/QSPI_I00: IC1.27 (PB1), IC2.5 (SI(IO0))
/QSPI_I01: IC1.26 (PB0), IC2.2 (SO(IO1))
/QSPI_I02: IC1.23 (PA7), IC2.3 (WP#(IO2))
/QSPI_I03: IC1.22 (PA6), IC2.7 (HOLD#_OR__RESET#(IO3))
/QSPI_NSS: IC1.16 (PA2), IC2.1 (CE#), R5.2
/SCL3: IC1.8 (PC0), J2.2
/SDA3: IC1.9 (PC1), J2.1
/SWCLK: IC1.49 (PA14), J1.4
/SWDIO: IC1.46 (PA13), J1.3
/USART1_CK: IC1.41 (PA8), J5.8
/USART1_CTS: IC1.44 (PA11), J5.9
/USART1_RTS: IC1.45 (PA12), J5.12
/USART1_RX: IC1.43 (PA10), J5.11
/USART1_TX: IC1.42 (PA9), J5.10
/VBAT: C15.1, IC1.1 (VBAT)
/VDD_FILT: C1.1, C2.1, C3.1, C4.1, C5.1, C6.1, C7.1, C8.1, C14.1, FB1.2, IC1.13 (VDDA/VREF+), IC1.19 (VDD_1), IC1.32 (VDD_2), IC1.48 (VDDUSB), IC1.64 (VDD_3), IC2.8 (VCC), R5.1
GND: C1.2, C2.2, C3.2, C4.2, C5.2, C6.2, C7.2, C8.2, C9.2, C10.2, C11.2, C12.2, C13.2, C14.2, C15.2, IC1.12 (VSSA/VREF-), IC1.18 (VSS_1), IC1.31 (VSS_2), IC1.47 (VSS_3), IC1.63 (VSS_4), IC2.4 (GND), J1.2, J4.3, J5.3, J6.1, J6.2, J6.3, J6.4, J8.2, LED1.1, LED2.1, R3.2, Y1.2 (GND_1), Y1.4 (GND_2)
unnamed 31: C10.1, IC1.6 (PH1-OSC_OUT), Y1.3 (CRYSTAL_2); also elsewhere on the board
unnamed 32: C11.1, IC1.5 (PH0-OSC_IN), Y1.1 (CRYSTAL_1); also elsewhere on the board
unnamed 33: C12.1, IC1.4 (PC15-OSC32_OUT), Y2.2; also elsewhere on the board
unnamed 34: C13.1, IC1.3 (PC14-OSC32_IN), Y2.1; also elsewhere on the board
unnamed: IC1.60 (PH3-BOOT0), R3.1, R4.2
unnamed: LED1.2, R1.2
unnamed: LED2.2, R2.2
VDD: FB1.1, J1.1

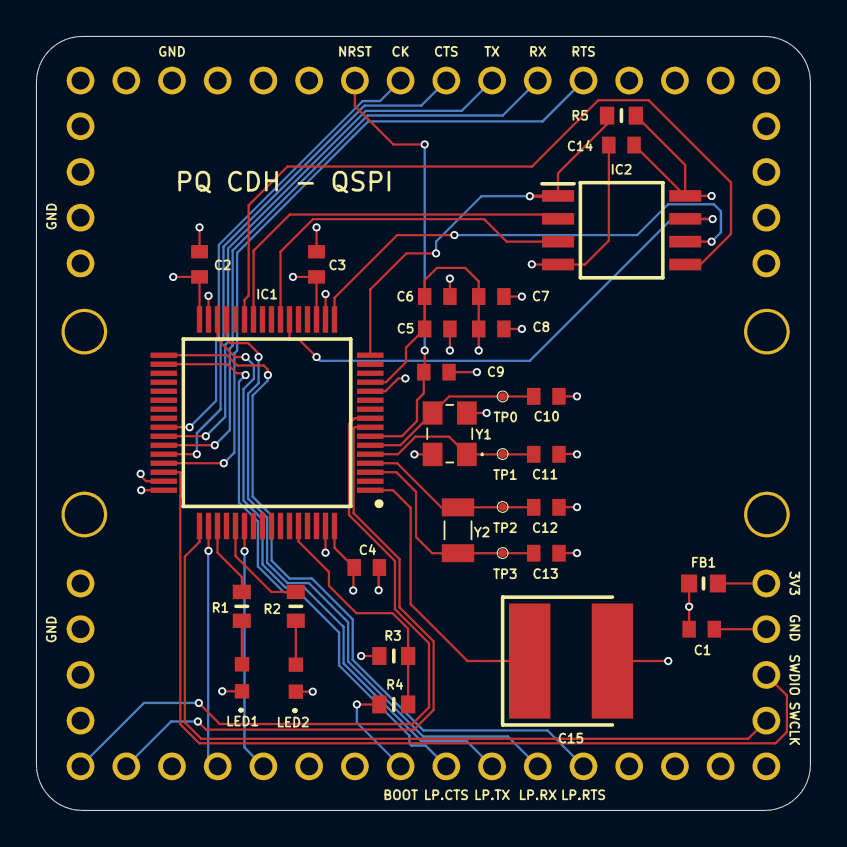
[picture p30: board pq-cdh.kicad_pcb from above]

Board: 4 copper layers, 43.0 x 43.0 mm, 36 parts (0 on the bottom side), 36 nets.

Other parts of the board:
TP: TP2; TestPoint_Pad_D1.0mm
TP#2: TP1; TestPoint_Pad_D1.0mm
TP#3: TP0; TestPoint_Pad_D1.0mm
TP#4: TP3; TestPoint_Pad_D1.0mm

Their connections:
unnamed 31: TP#3.1; also elsewhere on the board
unnamed 32: TP#2.2; also elsewhere on the board
unnamed 33: TP.3; also elsewhere on the board
unnamed 34: TP#4.4; also elsewhere on the board

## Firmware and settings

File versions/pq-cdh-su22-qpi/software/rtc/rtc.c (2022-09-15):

// bootloader.c
// Tartan Artibeus CDH board rtc implementation file
// rtc support library
// Written by Bradley Denby
// Other contributors: None
//
// See the top-level LICENSE file for the license.

// Standard library
#include <stdint.h>                 // uint8_t

// libopencm3 library
#include <libopencm3/cm3/scb.h>     // SCB_VTOR
#include <libopencm3/stm32/flash.h> // used in init_clock
#include <libopencm3/stm32/gpio.h>  // used in init_gpio
#include <libopencm3/stm32/rcc.h>   // used in init_clock
#include <libopencm3/stm32/usart.h> // used in init_uart
#include <libopencm3/stm32/rtc.h>
#include <libopencm3/stm32/pwr.h>


// rtc support library
#include </home/abstract/git-repos/pq-cdh-su22-master/software/rtc/pq-cdh/support.h>             // Header file

// Initialization functions
void set_rtc(void);

void set_rtc(void) {
  rtc_enable_bypass_shadow_register();
  rtc_calendar_set_year((uint8_t) 11);
  //RTC_DR = 0x00113109;
  usart_send_blocking(USART1, RTC_DR >> 16);
  
  //set RTC_DR_MT,      Date Register bit  [12] 
  //and RTC_DR_MU[3:0], Date Register bits [11:8]
  rtc_calendar_set_month((uint8_t) 11);

  //set RTC_DR_DT[1:0], Date Register bits [5:4] 
  //and RTC_DR_DU[3:0], Date Register bits [3:0]
  rtc_calendar_set_day((uint8_t) 12);
  usart_send_blocking(USART1, RTC_DR & 0xff);

  rtc_time_set_time((uint8_t) 10, (uint8_t) 0, (uint8_t) 0, false);
  rtc_set_am_format();

  rtc_clear_init_flag();
  rtc_lock();
  pwr_enable_backup_domain_write_protect();
}

int app_subroutine(int32_t seconds, int32_t nanoseconds);

int app_subroutine(int32_t seconds, int32_t nanoseconds) {
  int32_t JD = 2451545 + (43200 + seconds) / 86400;
  // int32_t JD = 2451545 + (seconds + 21600) / 86400;
  int32_t I, J, K, L, N;
  L = JD + 68569;
  N = 4 * L / 146097;
  L = L - (146097 * N + 3) / 4;
  I = 4000 * (L + 1) / 1461001;
  L = L - 1461 * I / 4 + 31;
  J = 80 * L / 2447;
  K = L - 2447 * J / 80;
  L = J / 11;
  J = J + 2 - 12 * L;
  I = 100 * (N - 49) + I + L;

  int32_t newJD = K - 32075 + 1461*(I + 4800 + (J - 14)/12)/4
                   + 367*(J - 2 - (J - 14)/12*12)/12 - 3
                   *((I + 4900 + (J - 14)/12)/100)/4;
  int32_t remainder = 43200 + seconds - (newJD - 2451545) * 86400; //seconds
  int32_t hour = remainder / 3600;
  int32_t min = (remainder % 3600) / 60;
  int32_t sec = (remainder % 3600) % 60;

  usart_send_blocking(USART1, (uint8_t) (I - 2000));
  usart_send_blocking(USART1, (uint8_t) J);
  usart_send_blocking(USART1, (uint8_t) K);
  /*
  usart_send_blocking(USART1, (uint8_t) ((JD >> 24) & 0xff));
  usart_send_blocking(USART1, (uint8_t) ((JD >> 16) & 0xff));
  usart_send_blocking(USART1, (uint8_t) ((JD >> 8) & 0xff));
  usart_send_blocking(USART1, (uint8_t) (JD & 0xff));
  usart_send_blocking(USART1, (uint8_t) ((newJD >> 24) & 0xff));
  usart_send_blocking(USART1, (uint8_t) ((newJD >> 16) & 0xff));
  usart_send_blocking(USART1, (uint8_t) ((newJD >> 8) & 0xff));
  usart_send_blocking(USART1, (uint8_t) (newJD & 0xff));*/
  usart_send_blocking(USART1, (uint8_t) hour);
  usart_send_blocking(USART1, (uint8_t) min);
  usart_send_blocking(USART1, (uint8_t) sec);

  
  //procedure to initialize rtc
  rcc_periph_clock_enable(RCC_PWR);
  pwr_disable_backup_domain_write_protect();
  rcc_osc_on(RCC_LSI);
  rcc_wait_for_osc_ready(RCC_LSI);
  rcc_set_rtc_clock_source(RCC_LSI);
  rcc_enable_rtc_clock();
  rtc_wait_for_synchro();
  rtc_unlock();
  rtc_set_init_flag();
  rtc_wait_for_init_ready();
  rtc_set_prescaler((uint32_t) 249, (uint32_t) 127);
  rtc_enable_bypass_shadow_register();

  //set RTC_DR_YT[3:0], Date Register bits [23:20] 
  //and RTC_DR_YU[3:0], Date Register bits [19:16]
  rtc_calendar_set_year((uint8_t) (I - 2000));
  
  //set RTC_DR_MT,      Date Register bit  [12] 
  //and RTC_DR_MU[3:0], Date Register bits [11:8]
  rtc_calendar_set_month((uint8_t) J);

  //set RTC_DR_DT[1:0], Date Register bits [5:4] 
  //and RTC_DR_DU[3:0], Date Register bits [3:0]
  rtc_calendar_set_day((uint8_t) K);
  
  rtc_set_am_format();
  //set RTC_TR_PM,       Time Register bit  [22]
  //and RTC_TR_HT[3:0],  Time Register bits [21:20]
  //and RTC_TR_HU[3:0],  Time Register bits [19:16]
  //and RTC_TR_MNT[3:0], Time Register bits [14:12]
  //and RTC_TR_MNU[3:0], Time Register bits [11:8]
  //and RTC_TR_ST[3:0],  Time Register bits [6:4]
  //and RTC_TR_SU[3:0],  Time Register bits [3:0]
  rtc_time_set_time((uint8_t) hour, (uint8_t) min, (uint8_t) sec, true);

  rtc_clear_init_flag();
  rtc_lock();
  pwr_enable_backup_domain_write_protect();
  
  //trivial return statement, currently has no way to set nanoseconds
  return nanoseconds * 0 + 1;
}

uint32_t app_read_time(void);

uint32_t app_read_time() {
  int32_t I = (int32_t) (((RTC_DR >> 20) * 10) + ((RTC_DR >> 16) & 0xf) + 2000); //year
  int32_t J = (int32_t) ((((RTC_DR >> 12) & 0x1) * 10) + ((RTC_DR >> 8) & 0xf)); //month
  int32_t K = (int32_t) ((((RTC_DR >> 4) & 0x3) * 10) + (RTC_DR & 0xf)); //day
  int32_t hour = (int32_t) ((((RTC_TR >> 20) & 0x3) * 10) + ((RTC_TR >> 16) & 0xf));
  int32_t minute = (int32_t) ((((RTC_TR >> 12) & 0x7) * 10) + ((RTC_TR >> 8) & 0xf));
  int32_t second = (int32_t) ((((RTC_TR >> 4) & 0x7) * 10) + (RTC_TR & 0xf));
  
  int32_t JD = K - 32075 + 1461*(I + 4800 + (J - 14)/12)/4
               + 367*(J - 2 - (J - 14)/12*12)/12 - 3
               *((I + 4900 + (J - 14)/12)/100)/4;
  int32_t JS = (JD - 2451545) * 86400 - 43200;
  int32_t additional = hour * 3600 + minute * 60 + second;
  uint32_t res = (uint32_t) (JS + additional);
  return res;
}

int main(void) {
  // Bootloader initialization
  init_clock();
  init_uart();
  init_led();
  app_subroutine(679674848, 640221000);
  while(1) {
    /*
    usart_send_blocking(USART1,'H');
    usart_send_blocking(USART1,'e');
    usart_send_blocking(USART1,'l');
    usart_send_blocking(USART1,'l');
    usart_send_blocking(USART1,'o');
    usart_send_blocking(USART1,' ');
    usart_send_blocking(USART1,'w');
    usart_send_blocking(USART1,'o');
    usart_send_blocking(USART1,'r');
    usart_send_blocking(USART1,'l');
    usart_send_blocking(USART1,'d');
    usart_send_blocking(USART1,'!');
    usart_send_blocking(USART1,'\r');
    usart_send_blocking(USART1,'\n');
    */
    gpio_toggle(GPIOC,GPIO10);
    for(int i=0; i<800000; i++) {
      __asm__("nop");
    }
  }
}

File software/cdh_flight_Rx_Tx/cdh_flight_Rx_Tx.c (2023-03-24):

// flight_401_blr.c
// Tartan Artibeus EXPT board flight 401 bootloader
//
// Written by Bradley Denby
// Other contributors: None
//
// See the top-level LICENSE file for the license.

// Standard library
#include <stddef.h>          // size_t
#include <stdint.h>          // fixed-width integer types

#include <libopencm3/stm32/flash.h>
#include <libopencm3/stm32/gpio.h>
#include <libopencm3/stm32/rcc.h>
#include <libopencm3/stm32/usart.h>

// support library
#include <support.h>      // microcontroller utility functions
#include <commands.h>        // generates tab commands for transmission
#include <bootloader.h>      // microcontroller utility functions
#include <taolst_protocol.h> // protocol utility functions
 // protocol utility functions

// Macros
#define PAGE_BUFFER_LEN 128
#define ASCII_BUFFER_LEN 24  // changed from 12 for testing
//#define CMD_MAX_LEN 258

// Constants
static const uint16_t HW_ID = 0x0012;

// Variables
static uint16_t msg_id = 0x00;
static char cmd_buffer[CMD_MAX_LEN];
static char page_buffer[PAGE_BUFFER_LEN];
static char ascii_buffer[ASCII_BUFFER_LEN];


//static char rece_buffer [CMD_MAX_LEN];

//// in_bootloader is an extern variable read by bootloader_running
int in_bootloader;

//// app_jump_pending is an extern variable modified in write_reply
int app_jump_pending;

//Helper Functions
static void uart_puts(const char* s, const size_t l) {
  for(size_t i=0; i<l; i++) {
    usart_send_blocking(USART1,s[i]);
  }
}

// Main
int main(void) {
  
  // Bootloader initialization
  init_clock();
  init_led();
  init_uart();


  // enabling pheripherals to control EPS board
  // IO pin ctrl to EPS
  rcc_periph_clock_enable(RCC_GPIOA);
  rcc_periph_clock_enable(RCC_GPIOD);
  rcc_periph_clock_enable(RCC_GPIOB);
  gpio_mode_setup(GPIOA, GPIO_MODE_OUTPUT, GPIO_PUPD_NONE, GPIO15);
  gpio_mode_setup(GPIOD, GPIO_MODE_OUTPUT, GPIO_PUPD_NONE, GPIO2);
  gpio_mode_setup(GPIOB, GPIO_MODE_ANALOG, GPIO_PUPD_NONE, GPIO2);
  gpio_set(GPIOA, GPIO15);
  gpio_set(GPIOD, GPIO2);

  //LED pin
  rcc_periph_clock_enable(RCC_GPIOC);
  gpio_mode_setup(GPIOC, GPIO_MODE_OUTPUT, GPIO_PUPD_NONE, GPIO10);
  gpio_mode_setup(GPIOC, GPIO_MODE_OUTPUT, GPIO_PUPD_NONE, GPIO12);

  
  rx_cmd_buff_t rx_cmd_buff = {.size=CMD_MAX_LEN};
  clear_rx_cmd_buff(&rx_cmd_buff);
  tx_cmd_buff_t tx_cmd_buff = {.size=CMD_MAX_LEN};
  clear_tx_cmd_buff(&tx_cmd_buff);

  // Application loop
  while(1) {
  
    
    rx_usart1(&rx_cmd_buff);           // Collect command bytes
	  gpio_toggle(GPIOC, GPIO10);
	
    reply(&rx_cmd_buff, &tx_cmd_buff); // Command reply logic
	
    tx_usart1(&tx_cmd_buff);           // Send a response if any
	  gpio_toggle(GPIOC, GPIO12);
      
    
    //usart_recv_blocking(USART1);
    //usart_send(USART1, usart_recv(USART1));
    
    
  }

	return 0;
}

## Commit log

2022-05-26 Adds essential files and directories
    [BOM.csv]
2022-05-31 pq-cdh_build_schematic_pcb_v1.0.1
    PCB, Schematic, Symbol, Project File
    [pq-cdh.kicad_pcb, pq-cdh.kicad_sch]
2022-06-01 With Changes related Ext Flash SPI configuration
    [pq-cdh-B_Courtyard.gbr, pq-cdh-B_Cu.gbr, pq-cdh-B_Fab.gbr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]
2022-06-01 Added crystal Oscillator 3D models
    [ABM8AIG25000MHZ122ZT3.stp, ABS07AIG32768kHz71T.stp]
2022-06-01 With Xtal 3D-models
    [pq-cdh-B_Courtyard.gbr, pq-cdh-B_Cu.gbr, pq-cdh-B_Fab.gbr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]
2022-06-01 Silkscreen_room update for IC2 and C15
    [pq-cdh-B_Courtyard.gbr, pq-cdh-B_Cu.gbr, pq-cdh-B_Fab.gbr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]
2022-06-01 Silkscreen nameupdate for IC2 and C15
    [pq-cdh.csv]
2022-06-03 Updated_BOM sheet v0.1.0
    [BOM.csv]
2022-06-03 latest_gerbers file
    [pq-cdh-B_Cu.gbr, pq-cdh-B_Mask.gbr, pq-cdh-B_Silkscreen.gbr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]
2022-06-03 Updated_BOM
    first order placed
    [BOM.csv]
2022-06-07 Added Order_status column
    [BOM.csv]
2022-06-09 v0.2.0
    Controller_adjustment
    [pq-cdh.kicad_pcb]
2022-06-10 v0.1.1_review_updates
    remove vias for SWDIO and SWCLK and connecting directly to lower right connectors
    [pq-cdh.kicad_pcb]
2022-06-10 v0.1.1_review_updates
    remove vias for SWDIO and SWCLK
    [pq-cdh-B_Cu.gbr, pq-cdh-B_Mask.gbr, pq-cdh-B_Paste.gbr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]
2022-06-10 pd-cdh_v0.1.1
    PCB ordered
2022-06-16 pd_cdh_v0.2.0
    - I2C3 SDA and SCL to pins 1 and 2 on the bottom header row
    - ADC to pin 3 on the bottom header row
    - unused GPIO to pins 4 and 5 on the bottom header row
    [pq-cdh.kicad_pcb, pq-cdh.kicad_sch]
2022-09-19 Added tests for transmission of TAB commands from CDH board
2022-09-20 MVP Spi flash chip -- somewhat buggy
    [offchip-flash.c, support.c]
2022-10-03 Updated git-ignore and added stm32 reference manual
2022-10-10 quad spi demo WIP
2022-11-03 QSPI version
    [0603ZA220JAT2A.stp, 0603ZC104JAT2A.stp, 0603ZC105JAT2A.stp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]
2022-12-08 Added version of cdh board utilizing updated tab.c/.h files
2023-05-03 Added HWID filter 0x5441 for constellation
